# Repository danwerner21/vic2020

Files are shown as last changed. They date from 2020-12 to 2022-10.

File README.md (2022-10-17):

# Vic-2020
A Vic-20 clone created with [almost] all readily available parts

## Introduction
This project is an implementation of a VIC-20 (mostly) compatible computer. The project is built using a combination of 1980's era components (7400-series logic) and more modern components- such as a modern 6502 variant and 512 KiB SRAM and 512 KiB Flash ROMs. The only hard to find component is the MOS 6560 VIC video chip -- and it is my hope to follow up this project with a project to replace that chip with a FPGA replacement, providing the open source community a full path to re-creating the VIC-20 with all new components.

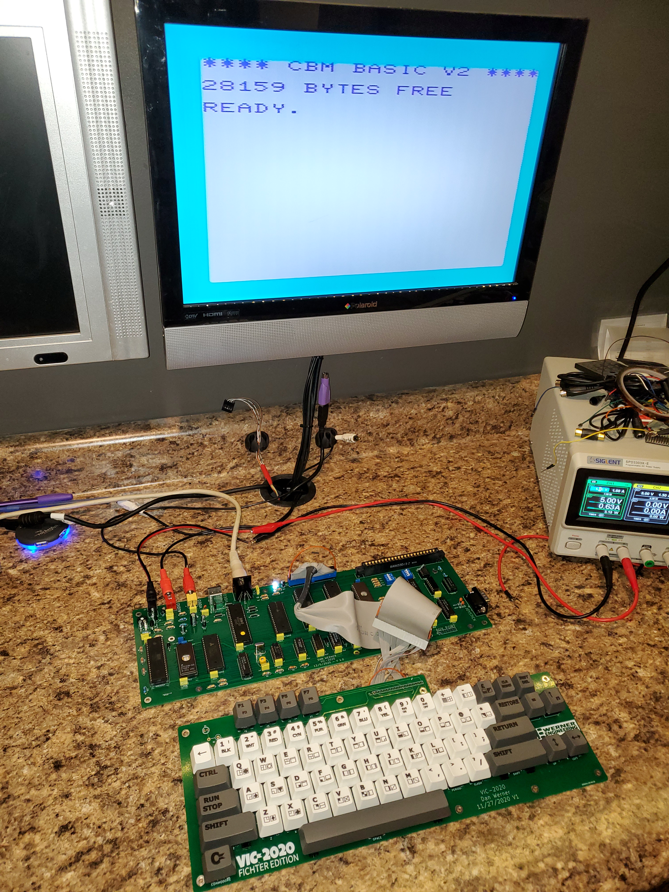
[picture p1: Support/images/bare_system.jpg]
Vic-2020 board set


## Why?
Why would I do a replica of the VIC-20?   Well, like many others the VIC-20 was my first computer.  In 1981 I spent most of my (non-school) waking hours learning everything possible about this machine, and that launched me into a successful career in IT.   In the early 2000s I discovered the retro-computer scene and have spent many hours building and creating new retro computer designs following the work happening in such places as 6502.org and retrobrewcomputers.org.  So much so, that my boss has taken to giving me crap about spending my free time "Building VIC-20s" . . . .   It was earlier in 2020 when he had made one such comment that I realized that while I had constructed many vintage designs, I had never actually built a VIC-20.  I decided that I should correct that oversight as soon as possible -- and thus the VIC-2020 Fichter Edition (named after my boss) was born.

---

## What is included in this repo?
As of this time, the repo includes

1. The VIC-2020 Mainboard PCB Kicad design and Gerber files
2. The VIC-2020 Keyboard PCB Kicad design and Gerber files
3. OpenSCAD and STL files for a 3d printed case
4. Design Files for Max Keyboard Custom Printed Keycaps

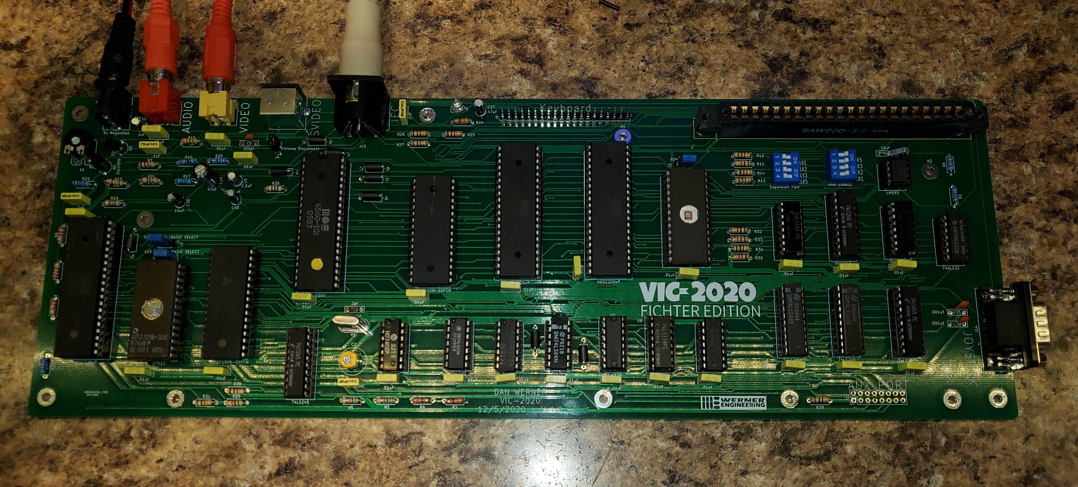
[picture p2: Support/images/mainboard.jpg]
Vic-2020 Mainboard

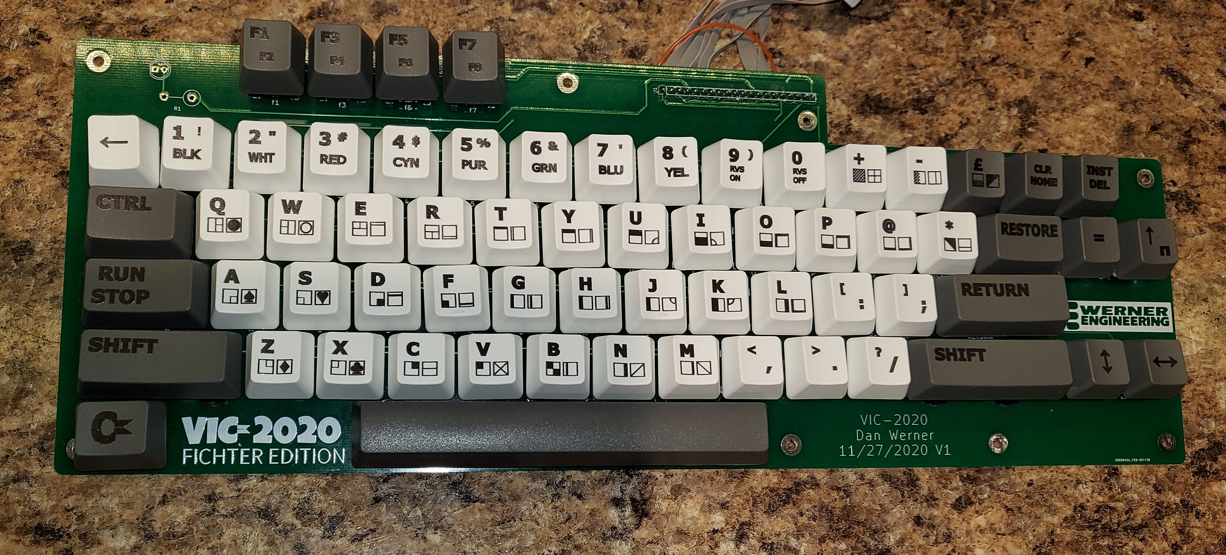
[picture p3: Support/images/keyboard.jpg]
Vic-2020 Keyboard

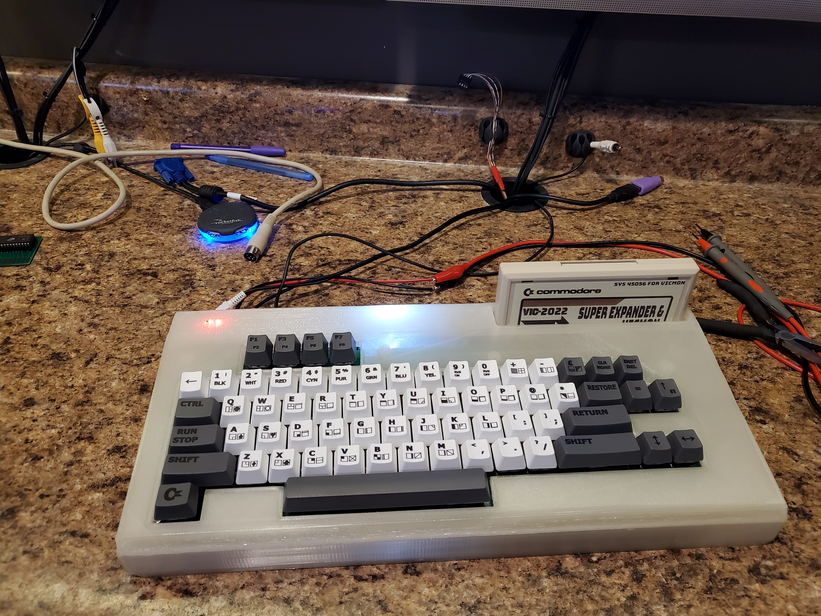
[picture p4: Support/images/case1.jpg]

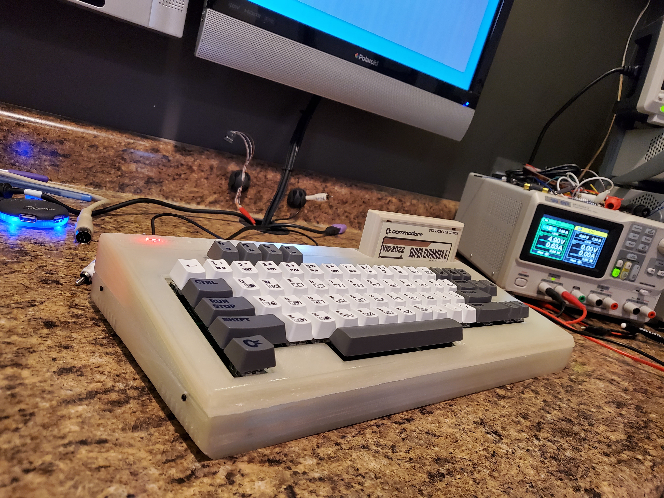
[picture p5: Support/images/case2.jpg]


---

## Known Bugs

* While the mainboard does have a S-VIDEO mod applied that should (in theory) provide S-VIDEO output, it does not work.   If anyone corrects this, please feel free to reach out and I will correct the schematics -- but for now, I would not populate the S-VIDEO connector, and always short the Chroma Disconnect jumper.
#### UPDATE
 Turns out the footprint for the SVIDEO connector in KiCad has the pins numbered incorrectly and that is the cause of the SVIDEO issue.   I have updated the PCB and Schematic to account for this, but have not tested the fix myself.  I am told that the SVIDEO out does work with a properly wired cable.

 note that the 1.1 version of the PCB still have the Chroma/Luma pins reversed on the video connector.  Seems that I made a patch to correct the pins and KiCAD also made a patch to correct the PCB layout of the connector, and thus reversed each other's work. . .  1.2 should be correct, but as always until it is tested, assume it needs patched.

---

## How is the VIC-2020 the same as a VIC-20?

The VIC-2020 should be mostly software compatible with the expanded and unexpanded Commodore VIC-20.   I have tested a variety of cartridges (commodore and third party) and have ran several homebrew and commercial disk based programs on the system with no issues.   Note that this does use a more modern variant of the 6502, so software relying on 6502 undocumented opcodes or bugs will not work properly.  The VIC-2020 has a commodore compatible IEC port that has been tested with a real 1571 and real 1541 and seems to work properly with one exception -- if the device holds the RESET line low the system will not function.   This can be observed if the VIC-2020 is connected to a powered off IED device -- the VIC will not function until the IEC device is powered on or unplugged from the VIC.

---

## How is the VIC-2020 different from a VIC-20?

Because the VIC-2020 is using more modern parts, it has ALOT of ram compared to the VIC-20.   The original VIC-20 shipped with 4k of ram . . .  the VIC-2020 has 256k.  This has some implications.   First, for compatibility there is a portion of the RAM that is just wasted. Of the 128k chip that is used for main memory, only 32k is accessible, the rest is hidden.  This is a design trade off that made the system less complex and ensured compatibility.   That said, small design changes were made to allow the 128k color ram to be totally usable by the system.  The first modification allowed all 8 bits of color ram to be used as storage for the system.  In the original VIC-20, color ram was only 4 bits wide, as the VIC chip only needs 4 bits to store color information.  In the VIC-2020 design all 8 bits are available to the CPU, even though only 4 bits are used by the VIC chip.  This should allow a programmer to store user information in the upper 4 bits of the color ram without affecting any other part of the system.   Also, the 6522 IO port that was dedicated to the user port on the VIC-20 has been repurposed as a "Page Register" (located at 0x9110 or 37136) on the VIC-2020 allowing 128 pages of color ram to be available for the VIC chip.  This should give the ability for some very interesting color effects to be produced on the VIC-2020, while still keeping the VIC mostly compatible.  This technique was demonstrated as early as 2010 in the sleepingelephant.com forums [here](http://sleepingelephant.com/ipw-web/bulletin/bb/viewtopic.php?t=4882).

### Power
Unlike the original, the VIC-2020 will run off of one regulated 5V 1.5A power supply.

### Ports
In order to simplify the VIC-2020s power requirements, the cassette and user ports were ommitted from the system.   It is possible to use the lines in the AUX connector (J11) and the IEC port to gain access to the cassette data lines if one wanted to use a cassette emulator.  The cartridge port is mostly compatible (assuming proper setting of SW3) with the omission of the RAM1,RAM2, & RAM3 lines.
Note that trimmer RV1 can be used to adjust video signal output strength.  If your particular TV appears either overdriven or too dim, adjust RV1 accordingly.   Variable Cap C2 can be used to adjust video signal phase -- adjust this trimmer if your VIC shows no color or the wrong colors.

### Ram Configuration
For simplicity sake, the VIC-2020 in even its lowest memory configuration has the VIC 3K memory expansion enabled at RAM1, RAM2, and RAM3, giving it 8K of base ram, 6.5k free for BASIC.   This configuration is totally compatible with most "unexpanded" VIC software, but is incompatible with any cartridge that includes the 3k RAM expansion option (such as the VIC Super Expander Cartridge).  The other RAM configuration options for BLK1, BLK2, BLK3, and BLK5 are DIP switch selectable allowing memory to be configured.   It is best to have each RAM block only assigned to either the Expansion Port (SW3) or the Internal RAM (SW1) but not both at the same time.  When in doubt set all of SW3 to "on" and all of SW1 to "off" and you should have a mostly compatible unexpanded VIC.  For a mostly compatible expanded VIC set BLK1,BLK2, BLK3 on SW1 to "on" and SW3 to "off".

### Character ROM Configuration
The 8K 2764 EPROM at U19 contains the character ROM image for the VIC-2020.  The VIC chip only needs 4K to store a complete set of character images, so jumper J3 is used to select one of two character sets that can be stored on the 2764.  If pins 1&2 are shorted on the jumper the first 4K of the chip is used (addresses 0x0000-0x0FFF) for the character patterns and if pins 2&3 are shorted the second 4K (addresses 0x1000-0x1FFF) are used.

### System ROM Configuration
On the VIC-2020 it is possible to use several different types of main ROM chips and have several ROM images burned at the same time -- all selected by jumpers J1 and J2.

Jumper Settings|Chip Used|Resulting eprom configuration
---------------|---------|-----------------------
J1 1&2, J2 1&2|27512         | BASIC image at 0x0000 through 0x1FFF KERNAL at 0x2000 through 0x3FFF
J1 1&2, J2 1&2|27256         | BASIC image at 0x0000 through 0x1FFF KERNAL at 0x2000 through 0x3FFF
J1 1&2, J2 1&2|27128         | BASIC image at 0x0000 through 0x1FFF KERNAL at 0x2000 through 0x3FFF
J1 1&2, J2 2&3|27512         | BASIC image at 0x4000 through 0x5FFF KERNAL at 0x6000 through 0x7FFF
J1 1&2, J2 2&3|27256         | BASIC image at 0x4000 through 0x5FFF KERNAL at 0x6000 through 0x7FFF
J1 1&2, J2 2&3|27128         | NOT VALID
J1 2&3, J2 1&2|27512         | BASIC image at 0x8000 through 0x9FFF KERNAL at 0xA000 through 0xBFFF
J1 2&3, J2 1&2|27256         | NOT VALID
J1 2&3, J2 1&2|27128         | NOT VALID
J1 2&3, J2 1&2|27512         | BASIC image at 0xC000 through 0xDFFF KERNAL at 0xE000 through 0xFFFF
J1 2&3, J2 1&2|27256         | NOT VALID
J1 2&3, J2 1&2|27128         | NOT VALID

---

## Bill Of Materials

### Mainboard

Part Number|Quantity|Name
-----------|--------|----
C35,C36	|2|	.001uf Capacitor
C7,C12-C34|	23|	.01uf Capacitor
C1,C6,C8,C10,C40|	5|	.1uf Capacitor
C37	|1|	.47uF Electrolytic Capacitor
C38	|1|	10uF Electrolytic Capacitor
C4	|1|	10uf Capacitor
C11	|1|	1uf Electrolytic Capacitor
C9	|1|	2.2uF Electrolytic Capacitor
C5	|1|	220pf Capacitor
C3	|1|	2pf Capacitor
C39	|1|	47uF Capacitor
C2	|1|	8-90pf  Variable Capacitor
FB1-FB9|	9|	Ferrite_Bead_Small
J1,J2,J3|	3|	Pin Header 1x03 2.54mm
J10	|1|	Barrel Jack
J11	|1|	Pin Header 2x8 2.54mm
J12	|1|	Card Edge Connector 2x22 (Mouser #:587-305-044-520-502)
J13	|1|	DIN 6 IEC connector (mouser#571-9-211509)
J14	|1|	DSUB 9 Male
J4,J9	|2|	Pin Header 1x2 2.54mm
J5	|1|	DIN-4 (mouser#571-5749181-1)
J6,J7	|2|	RCA Jack
J8	|1|	Pin Header 1x20
Q1	|1|	2sc1959
Q2	|1|	2SC1815
R36	|1|	75ohm Resistor 1/4w
R15	|1|	180ohm Resistor 1/4w
R16	|1|	240ohm Resistor 1/4w
R22	|1|	270ohm Resistor 1/4w
R2,R4,R24	|3|	330ohm Resistor 1/4w
R21	|1|	470ohm Resistor 1/4w
R17	|1|	510ohm Resistor 1/4w
R3,R5	|2|	560ohm Resistor 1/4w
R19	|1|	1.8Kohm Resistor 1/4w
R23	|1|	10Kohm Resistor 1/4w
R6	|1|	150Kohm Resistor 1/4w
R7,R11-R14,R18,R25-R35	|16|	1K ohm Resistor 1/4w
R8-R10	|3|	2.2Kohm Resistor 1/4w
R20	|1|	2.7Kohm Resistor 1/4w
R1	|1|	220kohm Resistor 1/4w
RV1	|1|	1Kohm Variable Resistor (Mouser# 531-PT10LV112A22PMS)
SW1,SW3	|2|	DIP Switch 4 pos
U19	|1|	2764
U20	|1|	6560 (MOS, VIC-20 pull or E-Bay)
U1	|1|	7402
U4	|1|	7406
U13	|1|	27512
U24	|1|	74ALS32
U8	|1|	74LS00
U11	|1|	74LS02
U9	|1|	74LS04
U5,U10	|2|	74LS133
U2,U6	|2|	74LS138
U14,U15,U16,U18,U23	|5|	74LS245
U12,U17	|2|	AS6C1008-55PCN
U3	|1|	LM555
U7	|1|	W65C02SxP
U21,U22	|2|	W65C22NxP
Y1	|1|	Crystal 14.31818Mhz

### Keyboard

Quantity|Name
--------|----
65|Cherry MX Switch | (Example Mouser 540-MX1A-11NW)
4|Switch Leveling Kit| Mouser 540-G99-0226 Note: Use one of 540-G99-0742 to build a through hole leveling kit for the spacebar
1|Pin Header 1x20
1|Pin Header 1x2 or LED
1|330 Ohm Resistor
1| Keycap set (See Max Keyboard Template to order custom keycaps)
1| 1x20 Female to Female dupont connector ribbon cable to connect keyboard to mainboard

### Case

The case for the Vic-2020 was created using openSCAD and was printed on the AnyCubic Chiron large format printer.   The OpenSCAD source files and the STL files are included in the archive.  The case is designed to allow you to install a power led in the upper left corner.   The opening is intended for two rectangular LEDs glued as shown here:

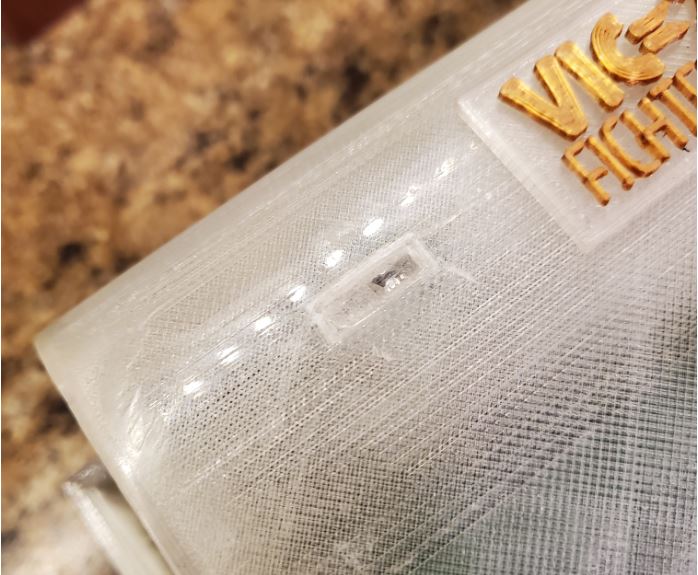
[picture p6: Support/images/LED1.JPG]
Case LED

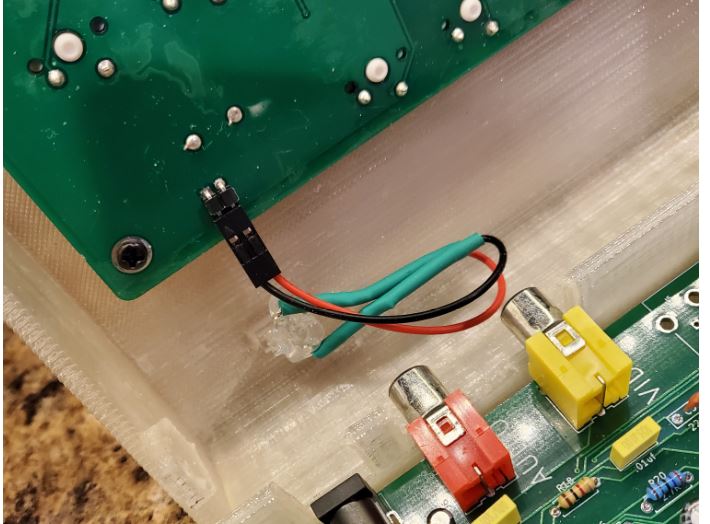
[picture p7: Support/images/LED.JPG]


It is also necessary to install a stabilizer on one corner of the keyboard to ensure that the keyboard PCB does not flex while typing.  This is how I did it:

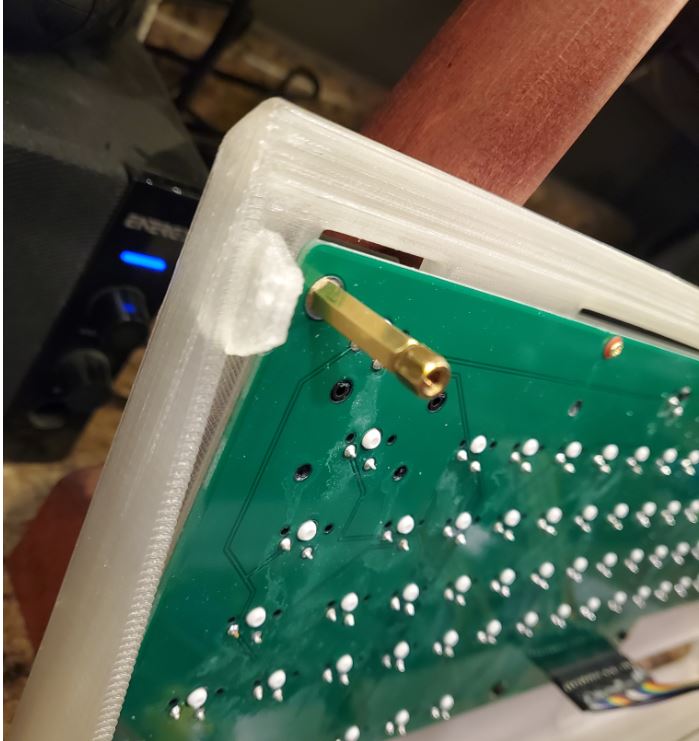
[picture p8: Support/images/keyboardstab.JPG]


When complete, the interior of the 3d printed case will look like this:

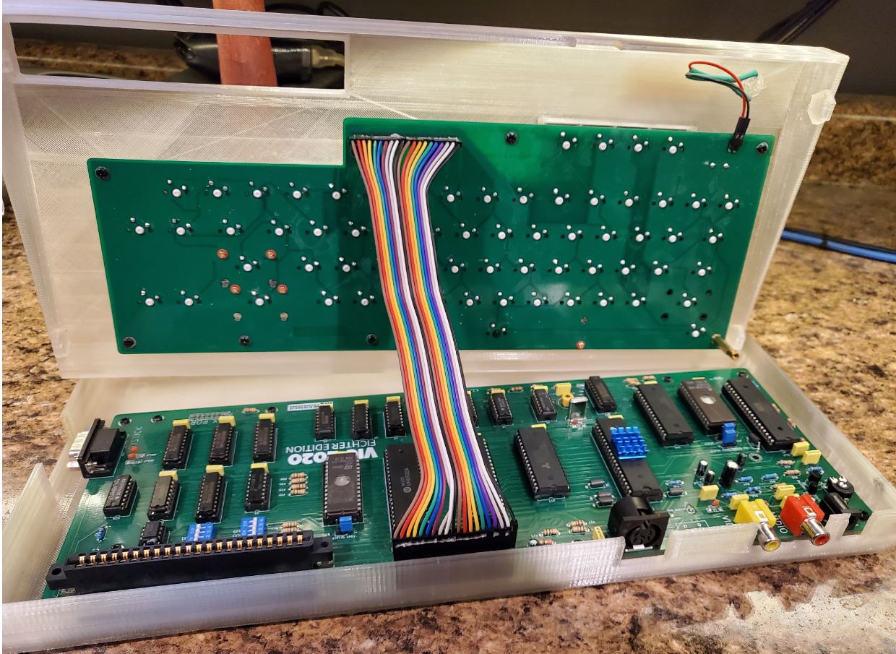
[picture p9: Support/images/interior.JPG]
Case internal


### Builder Comments

Below is a couple of observations from builders that might be useful in your build.  I have not tested any of these suggestions, just passing on collective wisdom :)

* One bulder commented that he needed to replace U9 (74LS04->74F04) and U11 (74LS02->74F02) with F series logic in order to get clean RAM access.   I have not had a need to do this on any of my builds, but timing is very tight on this board, and it is always possible that these substitutions would help clear up issues.  This same builder needed to use a Rockwell 65C02 in place of the WDC 65C02 to get a stable build.

* Another builder noted that is is important to use a 2764 EPROM for the character ROM.   A 27C64 EPROM caused graphical glitching when used.

* It was recently reported that at least one builder has had success using a 6561 PAL VIC chip to replace the 6560 NTSC VIC chip.  It is also necessary to replce the 14.31818Mhz crystal with a 4.433618 MHz crystal in a PAL system.

### Questions?

If there are any questions, I can be reached at vic2020Dan at gmail dot com.

---

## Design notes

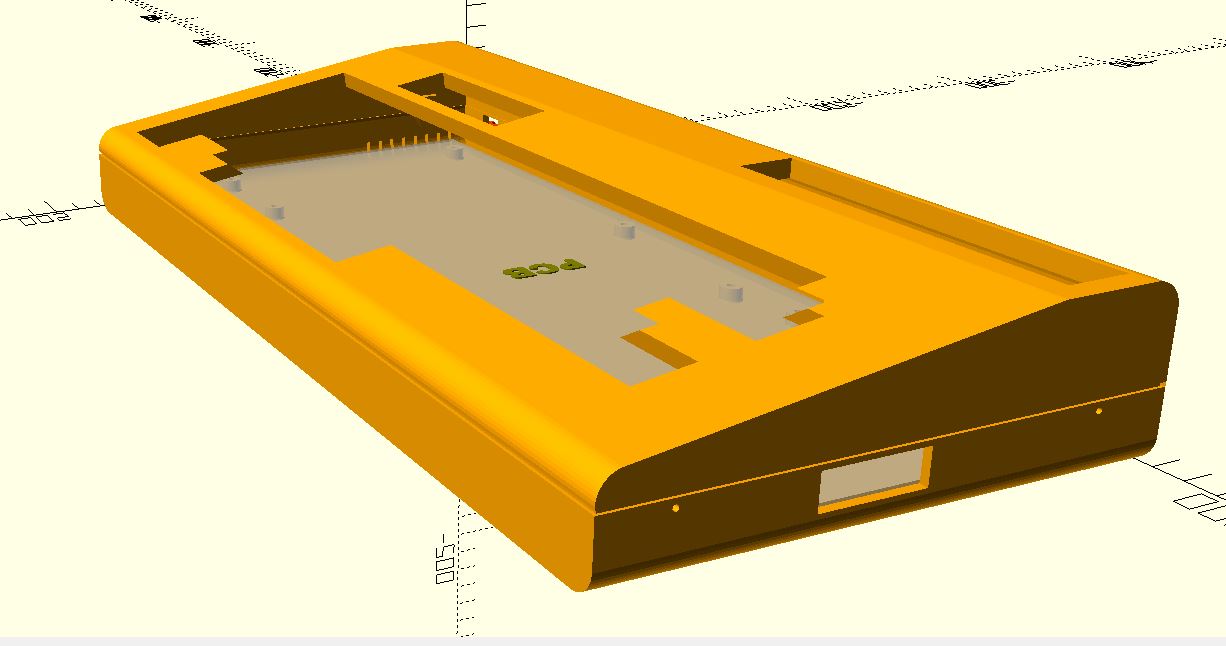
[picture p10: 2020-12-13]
Support/images/Case Render2.JPG

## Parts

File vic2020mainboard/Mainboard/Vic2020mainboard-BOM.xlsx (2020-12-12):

Reference | Qty | Value | Source
C35,C36 | 2 | .001uf Capacitor | mouser# 594-S102M33Z5UR63L6R
C7,C12-C34 | 23 | .01uf Capacitor | Capacitor_THT:C_Rect_L7.0mm_W2.0mm_P5.00mm
C1,C6,C8,C10,C40 | 5 | .1uf Capacitor | Capacitor_THT:C_Rect_L7.0mm_W2.0mm_P5.00mm
C37 | 1 | .47uF Electrolytic Capacitor | Capacitor_THT:CP_Radial_D4.0mm_P2.00mm
C38 | 1 | 10uF Electrolytic Capacitor | Capacitor_THT:CP_Radial_D4.0mm_P2.00mm
C4 | 1 | 10uf Capacitor | Capacitor_THT:C_Rect_L7.0mm_W2.0mm_P5.00mm
C11 | 1 | 1uf Electrolytic Capacitor | Capacitor_THT:CP_Radial_D4.0mm_P2.00mm
C9 | 1 | 2.2uF Electrolytic Capacitor | Capacitor_THT:CP_Radial_D4.0mm_P2.00mm
C5 | 1 | 220pf Capacitor | Capacitor_THT:C_Rect_L7.0mm_W2.0mm_P5.00mm
C3 | 1 | 2pf Capacitor | Capacitor_THT:C_Rect_L7.0mm_W2.0mm_P5.00mm
C39 | 1 | 47uF Capacitor | Capacitor_THT:CP_Radial_D4.0mm_P2.00mm
C2 | 1 | 8-90pf Variable Capacitor | Capacitor_THT:C_Radial_D10.0mm_H12.5mm_P5.00mm
FB1-FB9 | 9 | Ferrite_Bead_Small | Inductor_THT:L_Axial_L6.6mm_D2.7mm_P10.16mm_Horizontal_Vishay_IM-2
J1,J2,J3 | 3 | Pin Header 1x03 2.54mm | Connector_PinHeader_2.54mm:PinHeader_1x03_P2.54mm_Vertical
J10 | 1 | Barrel Jack | Connector_BarrelJack:BarrelJack_CUI_PJ-063AH_Horizontal
J11 | 1 | Pin Header 2x8 2.54mm | Connector_PinHeader_2.54mm:PinHeader_2x08_P2.54mm_Vertical
J12 | 1 | Card Edge Connector 2x22 (Mouser #:587-305-044-520-502) | Mouser #:587-305-044-520-502
J13 | 1 | DIN 6 IEC connector (mouser#571-9-211509) | 587-305-044-520-502
J14 | 1 | DSUB 9 Male | Connector_Dsub:DSUB-9_Male_Horizontal_P2.77x2.84mm_EdgePinOffset4.94mm_Housed_MountingHolesOffset7.48mm
J4,J9 | 2 | Pin Header 1x0 2.54mm | Connector_PinHeader_2.54mm:PinHeader_1x02_P2.54mm_Vertical
J5 | 1 | DIN-4 (mouser#571-5749181-1) | Connector:DIN-4TE_5749181-1
J6,J7 | 2 | RCA Jack | RCA:CUI_RCJ-041-reversepins
J8 | 1 | Pin Header 1x20 | Connector_PinHeader_2.54mm:PinHeader_1x20_P2.54mm_Vertical
Q1 | 1 | 2sc1959 | Package_TO_SOT_THT:TO-92_Inline_Wide
Q2 | 1 | 2SC1815 | Package_TO_SOT_THT:TO-92_Inline_Wide
R36 | 1 | 75ohm Resistor 1/4w | Resistor_THT:R_Axial_DIN0207_L6.3mm_D2.5mm_P7.62mm_Horizontal
R15 | 1 | 180ohm Resistor 1/4w | Resistor_THT:R_Axial_DIN0207_L6.3mm_D2.5mm_P7.62mm_Horizontal
R16 | 1 | 240ohm Resistor 1/4w | Resistor_THT:R_Axial_DIN0207_L6.3mm_D2.5mm_P7.62mm_Horizontal
R22 | 1 | 270ohm Resistor 1/4w | Resistor_THT:R_Axial_DIN0207_L6.3mm_D2.5mm_P7.62mm_Horizontal
R2,R4,R24 | 3 | 330ohm Resistor 1/4w | Resistor_THT:R_Axial_DIN0207_L6.3mm_D2.5mm_P7.62mm_Horizontal
R21 | 1 | 470ohm Resistor 1/4w | Resistor_THT:R_Axial_DIN0207_L6.3mm_D2.5mm_P7.62mm_Horizontal
R17 | 1 | 510ohm Resistor 1/4w | Resistor_THT:R_Axial_DIN0207_L6.3mm_D2.5mm_P7.62mm_Horizontal
R3,R5 | 2 | 560ohm Resistor 1/4w | Resistor_THT:R_Axial_DIN0207_L6.3mm_D2.5mm_P7.62mm_Horizontal
R19 | 1 | 1.8Kohm Resistor 1/4w | Resistor_THT:R_Axial_DIN0207_L6.3mm_D2.5mm_P7.62mm_Horizontal
R23 | 1 | 10Kohm Resistor 1/4w | Resistor_THT:R_Axial_DIN0207_L6.3mm_D2.5mm_P7.62mm_Horizontal
R6 | 1 | 150Kohm Resistor 1/4w | Resistor_THT:R_Axial_DIN0207_L6.3mm_D2.5mm_P7.62mm_Horizontal
R7,R11-R14,R18,R25-R35 | 16 | 1K ohm Resistor 1/4w | Resistor_THT:R_Axial_DIN0207_L6.3mm_D2.5mm_P7.62mm_Horizontal
R8-R10 | 3 | 2.2Kohm Resistor 1/4w | Resistor_THT:R_Axial_DIN0207_L6.3mm_D2.5mm_P7.62mm_Horizontal
R20 | 1 | 2.7Kohm Resistor 1/4w | Resistor_THT:R_Axial_DIN0207_L6.3mm_D2.5mm_P7.62mm_Horizontal
R1 | 1 | 220kohm Resistor 1/4w | Resistor_THT:R_Axial_DIN0207_L6.3mm_D2.5mm_P7.62mm_Horizontal
RV1 | 1 | 1Kohm Variable Resistor (Mouser# 531-PT10LV112A22PMS) | Varistor:Potentiometer_Trimmer_2x4.kicad_mod
SW1,SW3 | 2 | DIP Switch 4 pos | Package_DIP:DIP-8_W7.62mm
U19 | 1 | 2764 | Package_DIP:DIP-28_W15.24mm_Socket
U20 | 1 | 6560 (MOS, VIC-20 pull or E-Bay) | Package_DIP:DIP-40_W15.24mm_Socket
U1 | 1 | 7402 | Package_DIP:DIP-14_W7.62mm_Socket
U4 | 1 | 7406 | Package_DIP:DIP-14_W7.62mm_Socket
U13 | 1 | 27512 | Package_DIP:DIP-28_W15.24mm
U24 | 1 | 74ALS32 | Package_DIP:DIP-14_W7.62mm_Socket
U8 | 1 | 74LS00 | Package_DIP:DIP-14_W7.62mm_Socket
U11 | 1 | 74LS02 | Package_DIP:DIP-14_W7.62mm_Socket
U9 | 1 | 74LS04 | Package_DIP:DIP-14_W7.62mm_Socket
U5,U10 | 2 | 74LS133 | Package_DIP:DIP-16_W7.62mm_Socket
U2,U6 | 2 | 74LS138 | Package_DIP:DIP-16_W7.62mm_Socket
U14,U15,U16,U18,U23 | 5 | 74LS245 | Package_DIP:DIP-20_W7.62mm_Socket
U12,U17 | 2 | AS6C1008-55PCN | Package_DIP:DIP-32_W15.24mm
U3 | 1 | LM555 | Package_DIP:DIP-8_W7.62mm_Socket
U7 | 1 | W65C02SxP | Package_DIP:DIP-40_W15.24mm_Socket
U21,U22 | 2 | W65C22NxP | Package_DIP:DIP-40_W15.24mm_Socket
Y1 | 1 | Crystal 14.31818Mhz | Crystal:Crystal_HC18-U_Vertical

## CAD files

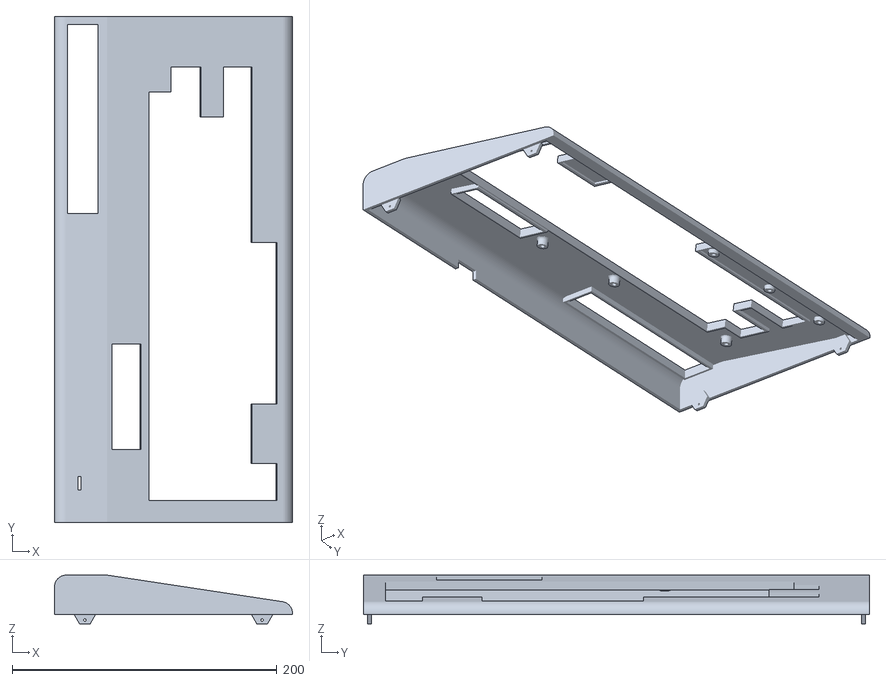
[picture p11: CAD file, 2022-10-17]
Support/Vic2020case_Top.stl
180.0 x 382.5 x 36.9

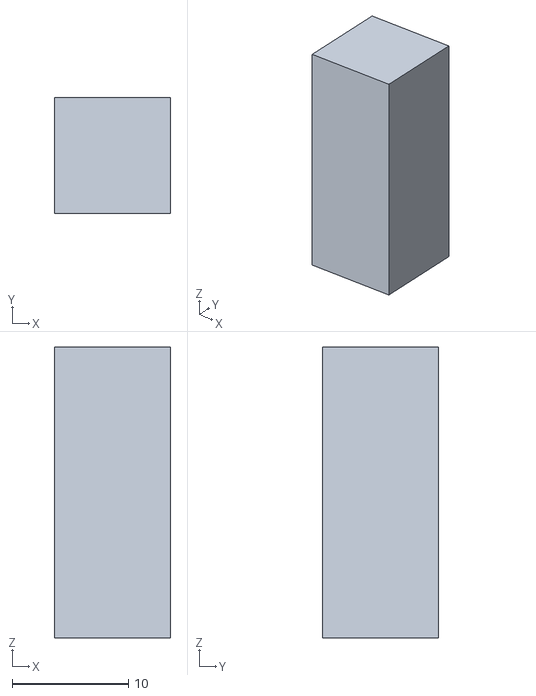
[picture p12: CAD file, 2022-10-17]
Support/Vic2020case_Keyboard_spacer.stl
10.0 x 10.0 x 25.0

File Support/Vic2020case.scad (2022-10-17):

/* [Box dimensions] */
  Length        = 180;       
  Width         = 385;                     
  TopHeight        = 10;  
  BottomHeight     = 25;  
  SlopeHeight      = 20;
  Thick         = 3;


  
/* [Box options] */
  PCBFeet       = 1;// [0:No, 1:Yes]
  Vent          = 1;// [0:No, 1:Yes]
  Vent_width    = 1.5;   



  Filet         = 9;//[0.1:12] 
  Resolution    = 50;//[1:100] 
  m             = 0.9;
  
/* [PCB_Feet--the_board_will_not_be_exported) ] */
//All dimensions are from the center foot axis
PCBPosX         = 0;
PCBPosY         = 0;
PCBLength       = 125;
PCBWidth        = 358;
FootHeight      = 9;
FootDia         = 8;
FootHole        = 4.4;  
  

/* [STL element to export] */
  TShell        = 0;// [0:No, 1:Yes]
  BShell        = 1;// [0:No, 1:Yes]
  RLogo         = 0;// Logo
  Spacer         = 0;// keyboard Spacer


  
/* [Hidden] */
Couleur1        = "Orange";       
Couleur2        = "OrangeRed";    
Dec_Thick       = Vent ? Thick*2 : Thick; 
Dec_size        = Vent ? Thick*2 : 0.8;

PCBL=PCBLength;
PCBW=PCBWidth;

   
module SlopeRoundBox($a=Length, $b=Width, $c=TopHeight+BottomHeight){
                    $fn=Resolution;     
                         
                        translate([Filet,-Filet/2,Filet])
                        {  
                    minkowski ()
                    {  
              
                    translate([0,($b/2)+1,TopHeight])
                       rotate(a=[0,-90,90])
                          linear_extrude(height =(($b/2)-Filet/2)+1, center = false, convexity = 0, twist = 0)
                              polygon(points=[[0,0],[(SlopeHeight+TopHeight)*-1,0],[(SlopeHeight+TopHeight)*-1,-30],  [TopHeight*-1,($a-Filet*2)*-1],[0,($a-Filet*2)*-1]], paths=[[3,2,1,0]]);                      
                        
                     rotate([270,0,0]){    
                        cylinder(r=Filet,h=Width/2+1, center = false);
                            } 
                        }
                    }
                }// End of RoundBox Module                


module RoundBox($a=Length, $b=Width, $c=TopHeight+BottomHeight){
                    $fn=Resolution;            
                    translate([0,Filet,Filet]){  
                    minkowski (){                                              
                        cube ([$a-(Length/2),$b-(2*Filet),$c-(2*Filet)], center = false);
                        rotate([0,90,0]){   
                           translate([0,0,Filet]){  
                        cylinder(r=Filet,h=Length/2-(2*Filet), center = false);}
                            } 
                        rotate([270,0,0]){    
                        cylinder(r=Filet,h=.1, center = false);
                            } 
                        }
                    }
                }// End of RoundBox Module



module TopShell(){
    Thick = Thick*2;  
    difference(){    
        difference(){
            union(){    
                     difference() {
                      
                        difference(){
                            union() {
                                        KeyboardCutoutReinforcement();

                            difference(){
                                SlopeRoundBox();
                                translate([Thick/2,Thick/2,Thick/2]){     
                                        SlopeRoundBox($a=Length-Thick*2, $b=Width-Thick*2, $c=TopHeight+BottomHeight-Thick);
                                        }
                                        }
                                    }
                               translate([-Thick,-Thick,TopHeight]){
                                   cube ([Length+100, Width+100, TopHeight+BottomHeight], center=false);
                                            }                                            
                                      }
                                }                                          

                difference(){
                    union(){
                        translate([3*Thick +5,Thick,TopHeight]){
                            rotate([90,0,0]){
                                    $fn=6;
                                    cylinder(d=16,Thick/2);
                                    }   
                            }
                            
                       translate([Length-((3*Thick)+5),Thick,TopHeight]){
                            rotate([90,0,0]){
                                    $fn=6;
                                    cylinder(d=16,Thick/2);
                                    }   
                            }

                    translate([3*Thick +5,Width-Thick/2-2.4,TopHeight]){
                            rotate([90,0,0]){
                                    $fn=6;
                                    cylinder(d=16,Thick/2);
                                    }   
                            }
                            
                       translate([Length-((3*Thick)+5),Width-Thick/2-2.4,TopHeight]){
                            rotate([90,0,0]){
                                    $fn=6;
                                    cylinder(d=16,Thick/2);
                                    }   
                            }


                        }
                            
                    } 
                    
                    
            }

       }


///Put Difference Keyboard Cutout Here

            union(){ //sides holes
                $fn=50;
                translate([3*Thick+5,20,TopHeight+4]){
                    rotate([90,0,0]){
                    cylinder(d=2,20);
                    }
                }
                translate([Length-((3*Thick)+5),20,TopHeight+4]){
                    rotate([90,0,0]){
                    cylinder(d=2,20);
                    }
                }
                translate([3*Thick+5,Width+5,TopHeight+4]){
                    rotate([90,0,0]){
                    cylinder(d=2,20);
                    }
                }
                translate([Length-((3*Thick)+5),Width+5,TopHeight+4]){
                    rotate([90,0,0]){
                    cylinder(d=2,20);
                    }
                }
            }

         // IEC Opening    
            translate([-1,(Thick)+243.8,Thick-3]){
              cube([21,21,BottomHeight-7]);
            }   


        KeyboardCutout();

        }
        KeyboardFeet();
        
       

}





module BottomShell(){
    Thick = Thick*2;  
    translate([0,2,0]){
    
    difference(){    
        difference(){
            //Main Box
            union(){    
                     difference() {
                      
                        difference(){
                            union() {
                            difference(){
                                RoundBox($a=Length, $b=Width-2, $c=TopHeight+BottomHeight);
                                translate([Thick/2,Thick/2,Thick/2]){     
                                        RoundBox($a=Length-Thick, $b=Width-Thick-2, $c=TopHeight+BottomHeight-Thick);
                                        }
                                        }

                                    }
                               translate([-Thick,-Thick,BottomHeight]){
                                   cube ([Length+100, Width+100, TopHeight+BottomHeight], center=false);
                                            }                                            
                                      }
                                }                                          


              
            }

       
            // vent holes
            union(){           
            for(i=[0:Thick:Length/4]){
                    translate([10+i,-Dec_Thick+Dec_size,1]){
                    cube([Vent_width,Dec_Thick,BottomHeight/2]);
                    }
                    translate([(Length-10) - i,-Dec_Thick+Dec_size,1]){
                    cube([Vent_width,Dec_Thick,BottomHeight/2]);
                    }
               
                  }
                }
                
        
            // Joystick Opening    
            translate([79,Width-Dec_size-2,Thick+4]){    
              cube([35,Dec_Thick+2,BottomHeight-5]);
            }
                

            // Power Opening    
            translate([-1,(Thick)+13.6,Thick+4]){
              cube([12,13,BottomHeight-11]);
            }   

            // Audio Opening    
            translate([-1,(Thick)+33.7,Thick+4]){
              cube([12,13,BottomHeight-11]);
            }   

            // Video Opening    
            translate([-1,(Thick)+55.5,Thick+4]){
              cube([12,13,BottomHeight-11]);
            }   

            // S-Video Opening    
          //  translate([-1,(Thick)+78.5,Thick+4]){
         //     cube([15,16,BottomHeight-9]);
         //   }
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

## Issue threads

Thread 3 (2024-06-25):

more for collective wisdom (things I've learnt along the way)

giobbino, 2024-06-25:
Finally I got a boot screen so I wish to share my experience with future builders...

- I do confirm that you can use PAL 6561-101 VIC chip. You need to use a 4.433618 MHz crystal (as as described in the readme.md) **AND** the PAL Kernal.
For the sake of simplicity, I'm attaching here a zip with the PAL Kernal ROM (both 256k and 512k). It also include a dual char ROM; you can swap between VIC-20 and C=64 characters generator (I've noticed you can swap it on the fly, without to switch off the computer).

[VIC2020 PAL kernal and char ROM.zip](https://github.com/user-attachments/files/15962549/VIC2020.PAL.kernal.and.char.ROM.zip)

- I also can confirm that you can use ATMEL AT28C256 for Basic + Kernal and ATMEL AT28C64 for char generator. I tried a Thompson 2764A EPROM, but it didn't work for me.

- Due to a different architecture from the original VIC-20, You **MUST** place the two 65C22 chips (U21 and U22) into their own sockets or the computer will not boot _(different from the Commodore computers, from PET, to VIC-20, C=64 and so on, where you usually remove those two chips during the debugging operation, since they're not needed for the computer to boot, but can lead to a black screen if bad)_

I'm using Rockwell R65C02 and R65C22, and some 74F chips as described in the readme.md

------

Now I'm going to build the keyboard, I was happy to see the welcome screen after some initial issues, so I decided to resume here some suggestions before to forget what I did.

danwerner21, 2024-06-26:
appreciate the feedback!  I will get this added to the readme file as soon as I get some time!

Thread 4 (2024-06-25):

suggestion about the cartridge connector

giobbino, 2024-06-25:
On Aliexpress (that, for many of us, is way cheaper than Mouser, also due to the shipping fee) you can find only this type of edge connector for that pitch (I didn't find any other):

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

Unfortunately it has bigger pins than the respective holes on the mainboard. I will try to drill the mainboard a little to fit that connector, but you maybe would update the Gerber with bigger holes for future builders.

Cheers,
Giovi

danwerner21, 2024-06-26:
appreciate the feedback, will try to get it incorporated in!

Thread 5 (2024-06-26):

it hardly boots

giobbino, 2024-06-26:
(Note: I suspect the issue I'm having have to do with fake ICs, especially fake Rockwell 65C02 / 65C22).

When I power on the board, usually does nothing, not even a black screen. It's totally out of signal, no raster.
At the beginning I suspected it was something (spike?) related with the lack of a power-on switch, so I added one. No changes.

However I noticed If I give a little tap on the switch, removing the power to the board for a very little instant (enough for the LED to blink, however), often the computer boot or at least starts to boot: mostly it lead to a black screen (with raster) that can converted in a normal boot screen using a reset switch between pins #3 and #8 of the 555.

I also noticed that the same behavior happens with a fake MOS 6502 I've bought on Aliexpres for a couple of bucks (so this leads me to believe the Rockwell 65C02 is a fake too).

Any idea about how to solve this problem?  BTW I've seen the decoupling capacitors are all 10 uF, while in most projects is used the 100 uF. Could it have something to do with that?

I've bought some more Rockwell ICs, but nobody grants they're legit and not (again!) fake. Unfortunately buying from Mouser or Digikey is not feasible; shipping to Brazil would cost more than 50 US$, because the haven't a cheap shipping option like Aliexpress.

danwerner21, 2024-06-26:
I am not sure about the fake 65C02s -- I have not had that issue (I usually do not use aliexpress -- for that very reason).

There are a couple of other things you might check though.   There are a few chips where logic family REALLY matters.   I would make sure that U4 is a 7406 and not a 74LS06 or any other family.   Same with U1 -- the 7402 needs to be a 7402.  The last important one is U24 -- it needs to be a 74ALS32.

Checking those chips would be the first place I would start looking.

Dan

giobbino, 2024-06-27:
Dan, thanks for your answer, it seems you pointed me in the right direction, albeit the results are different from the expected.

At first I did a test I should have done before: I checked with the scope the wave signal at the crystal pins... result, when the computer didn't boot there was a  very strange wave frequency (13.2 MHz) or just some noisy wave at 38.2 Mhz). So I replaced the crystal and later also the variable capacitor. No changes.

Of course I used 7606, 73ALS32 and 7402. I got this last one from my working, fully socketed VIC-20 I uses for tests etc. - BTW _The interesting part is that I replaced it with a 74LS02 and the VIC-20 still worked fine._

The 7402 I got from the VIC-20 had quite a recent date stamp; so I began wondering if it could be a fake CMOS labelled as 7402 as sometimes/often happens (however for some reason it worked into the VIC-20).

Since the VIC-20 worked fine with a 74LS02 in place of the 7402, I thought "why not?"... I got an old, legit 74LS02 and I put in the VIC2020.

Result: now the VIC2020 works fine, or at least it didn't fail anymore. So apparently a good 74LS02 in place of the 7402 can be used for the VIC2020. I will keep testing it and keep you informed.

My question is: what is the difference between 74 and 74LS ? AFAIK both should be NMOS, and LS was just a lower mA... and I can't find any different answer from the web.

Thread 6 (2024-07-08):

S-VIDEO / AUDIO correction

kinmami, 2024-07-08:
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

h[ttps://www.pcbway.com/project/shareproject/Commodore_VIC_20_MOS_6560_6561_Audio_Video_Booster_Adapter_726e273e.html](url)

To correct and improve the video and audio circuit of the MOS 6560/6561, please refer to my project and schematic. I hope it proves helpful. Regards, Edoardo

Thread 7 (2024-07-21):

VIC2020 and Tapuino

giobbino, 2024-07-21:
Hi,
I've built the first one, adding inside an SD2IEC, and now I'm planning to build the second and last one, but this I wish to put inside a Tapuino with display and buttons directly integrated into the case.

You said on could use the aux and iec ports for that purpose, but I don't understand how.
Can you kindly explain how to connect a Tapuino to the VIC2020?

BTW there are many versions of the Tapuino; the link to simple the project I'm going to use is: https://github.com/sweetlilmre/tapuino

danwerner21, 2024-07-21:
Sorry, but I do not know much about the tapunio  . . . but I expect would think that  what you are suggesting will work just fine.

giobbino, 2024-07-21:
Thanks for your answer! My only doubt, before to do a test, was about the WRITE line. I will try soon and report here the result!

BTW Tapuino is just a datassette emulator; it uses all the datassette lines, but of course - since it has no motor - it doesn't drain almost any power from the motor line.
The motor line is used to switch on/ff the IR transmitter of an optocoupler. I'm not sure if the 6522 supplies enough power for that, but just in case, a transistor should solve. I will take a look to the 6522 datasheet to see if I can any useful info there.

giobbino, 2024-07-23:
OK, i got the thing working in my 2nd VIC-2020 :-)

As told before, I used this version of Tapuino: [https://github.com/sweetlilmre/tapuino](https://github.com/sweetlilmre/tapuino) that's cheap, easy to build and can be embedded into the VIC-2020 _(I will put the display and the button in the place of the cartridge port, modifying the 3D project, since I don't need it - I have enough VIC-20s for that purpose and however I don't use cartridges a lot...  actually I seldom use the VIC-20, and I don't even know why I've built two VIC-2020 LOL)_

However, it requires some little modifications.

1) the AUX connector pin #16 must to be repurposed: cut the copper trace, check with a multimeter that it's no longer connected to GND and link it with a piece of wire to U22 pin #13. That's the WRITE line _(BTW strange that the aux connector hasn't it natively... maybe in a future revision?)_

2) the motor line is HIGH when the motor is off, and LOW when the motor is on; in the real VIC-20 it is connected to a small circuit of 3 transistors that inverts the signal and also add the needed power to move the C2N motor, but for the Tapuino we need to manage it someway.
In the attached schematics (see below, please forgive me the rather bad design LOL) you can find the modification at the original Tapuino schematics. It will require just an NPN transistor (I used a BC547 and it worked well).

In Tapuino, don't forget to enter into the Options and set Machine = VIC.

Hope it could help somebody.

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

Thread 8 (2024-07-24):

Equivalent ICs that worked (for me)...

giobbino, 2024-07-24:
Hi,
I just wish to leave some more info for the future builders...

NOTE: MY VERSION IS PAL (6561-101 and 4.433618 Mhz crystal) - some components listed here could not work in the NTSC version.

This is the logic glue I tested. What is not listed here is because I didn't test since I haven't different IC version in my tool box (74LS133, 74LS04 and 7406).

74ALS32  --> 74HC32; 74LS32
74LS245   --> 74HCT245
74LS138   --> 74HCT138
74LS02 	 --> 74HCT02
7402	 --> 74LS02  _(but not 74HCT02)_
74LS00     --> 74HCT00

I also verified that original MOS 6502 and MOS 6522 work too.

More: I tested those "fake MOS" 6502 that you can find for a couple of bucks or less on Aliexpress: they work too!

Actually those 6502  aren't fake 6502, just the "MOS" label is. They work; sometimes in a bunch of five or ten you can find one that  doesn't, but usually they're all ok. I suppose they're 6502 that come from some bad lot; they sanded the original label and wrote another one... so it could happen that after few days/months or in a specific configuration can hang...  but it's just what I'm guessing; I've not did an extensive test yet.

danwerner21, 2024-09-17:
Thanks for the feedback, I will try to get this incorporated into the README file!

Dan

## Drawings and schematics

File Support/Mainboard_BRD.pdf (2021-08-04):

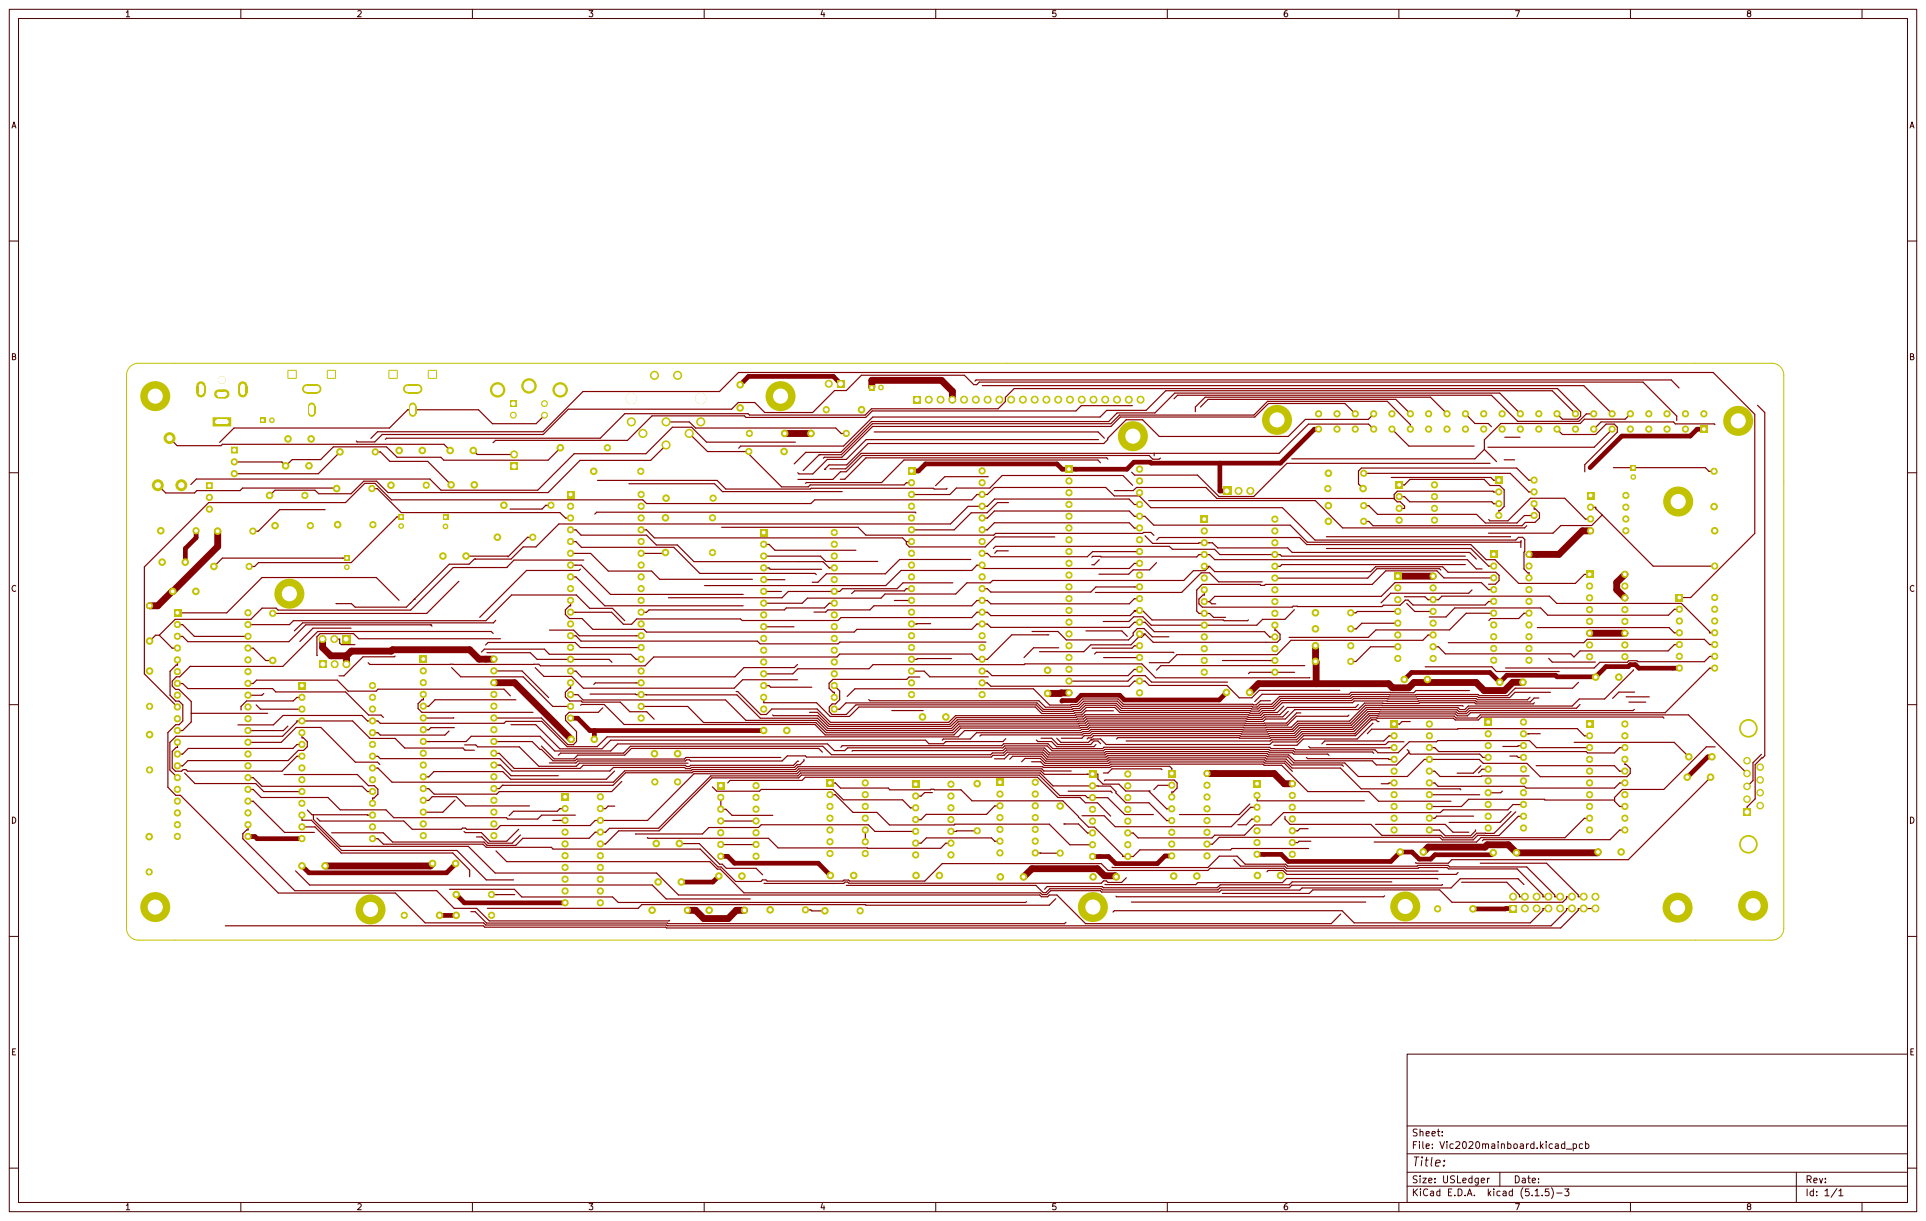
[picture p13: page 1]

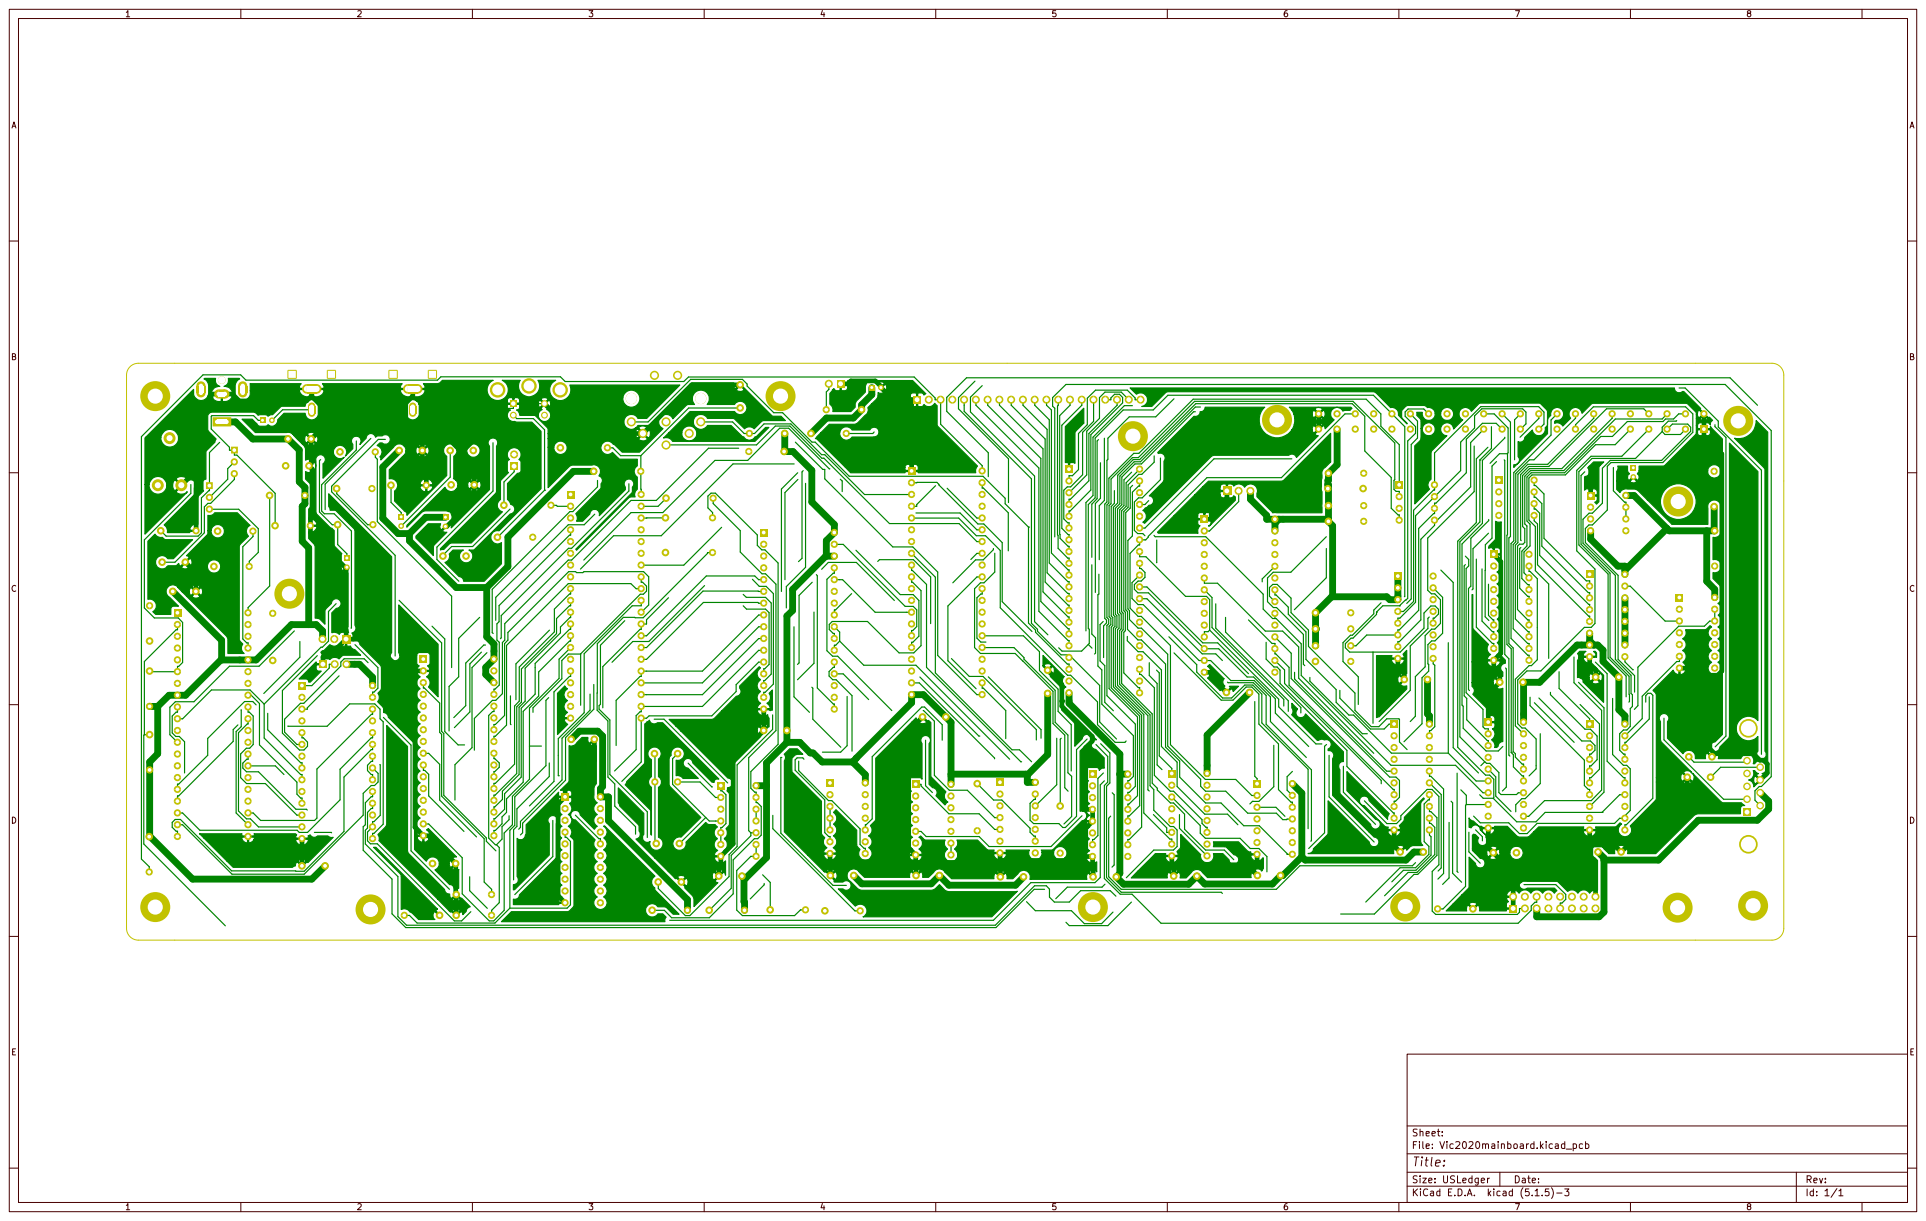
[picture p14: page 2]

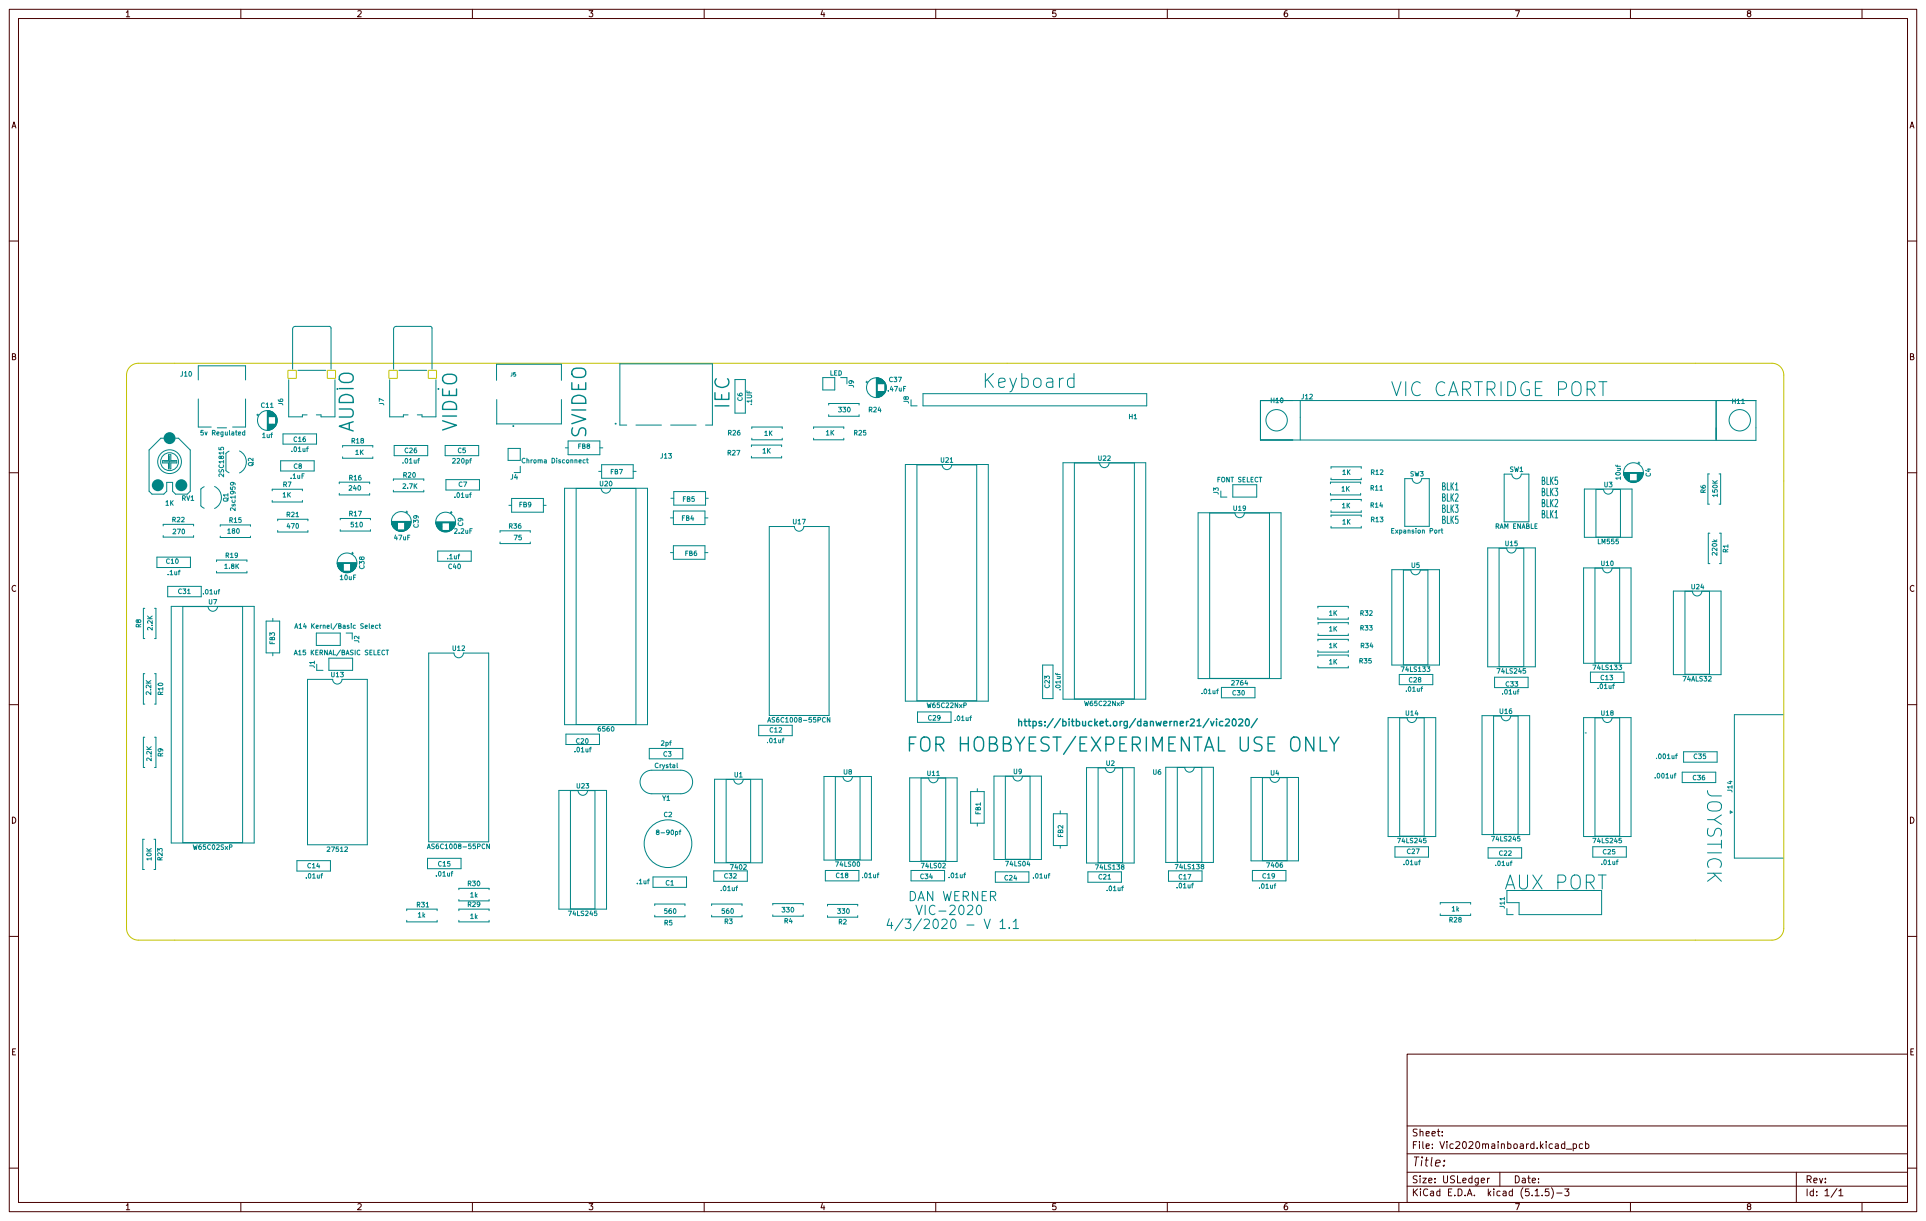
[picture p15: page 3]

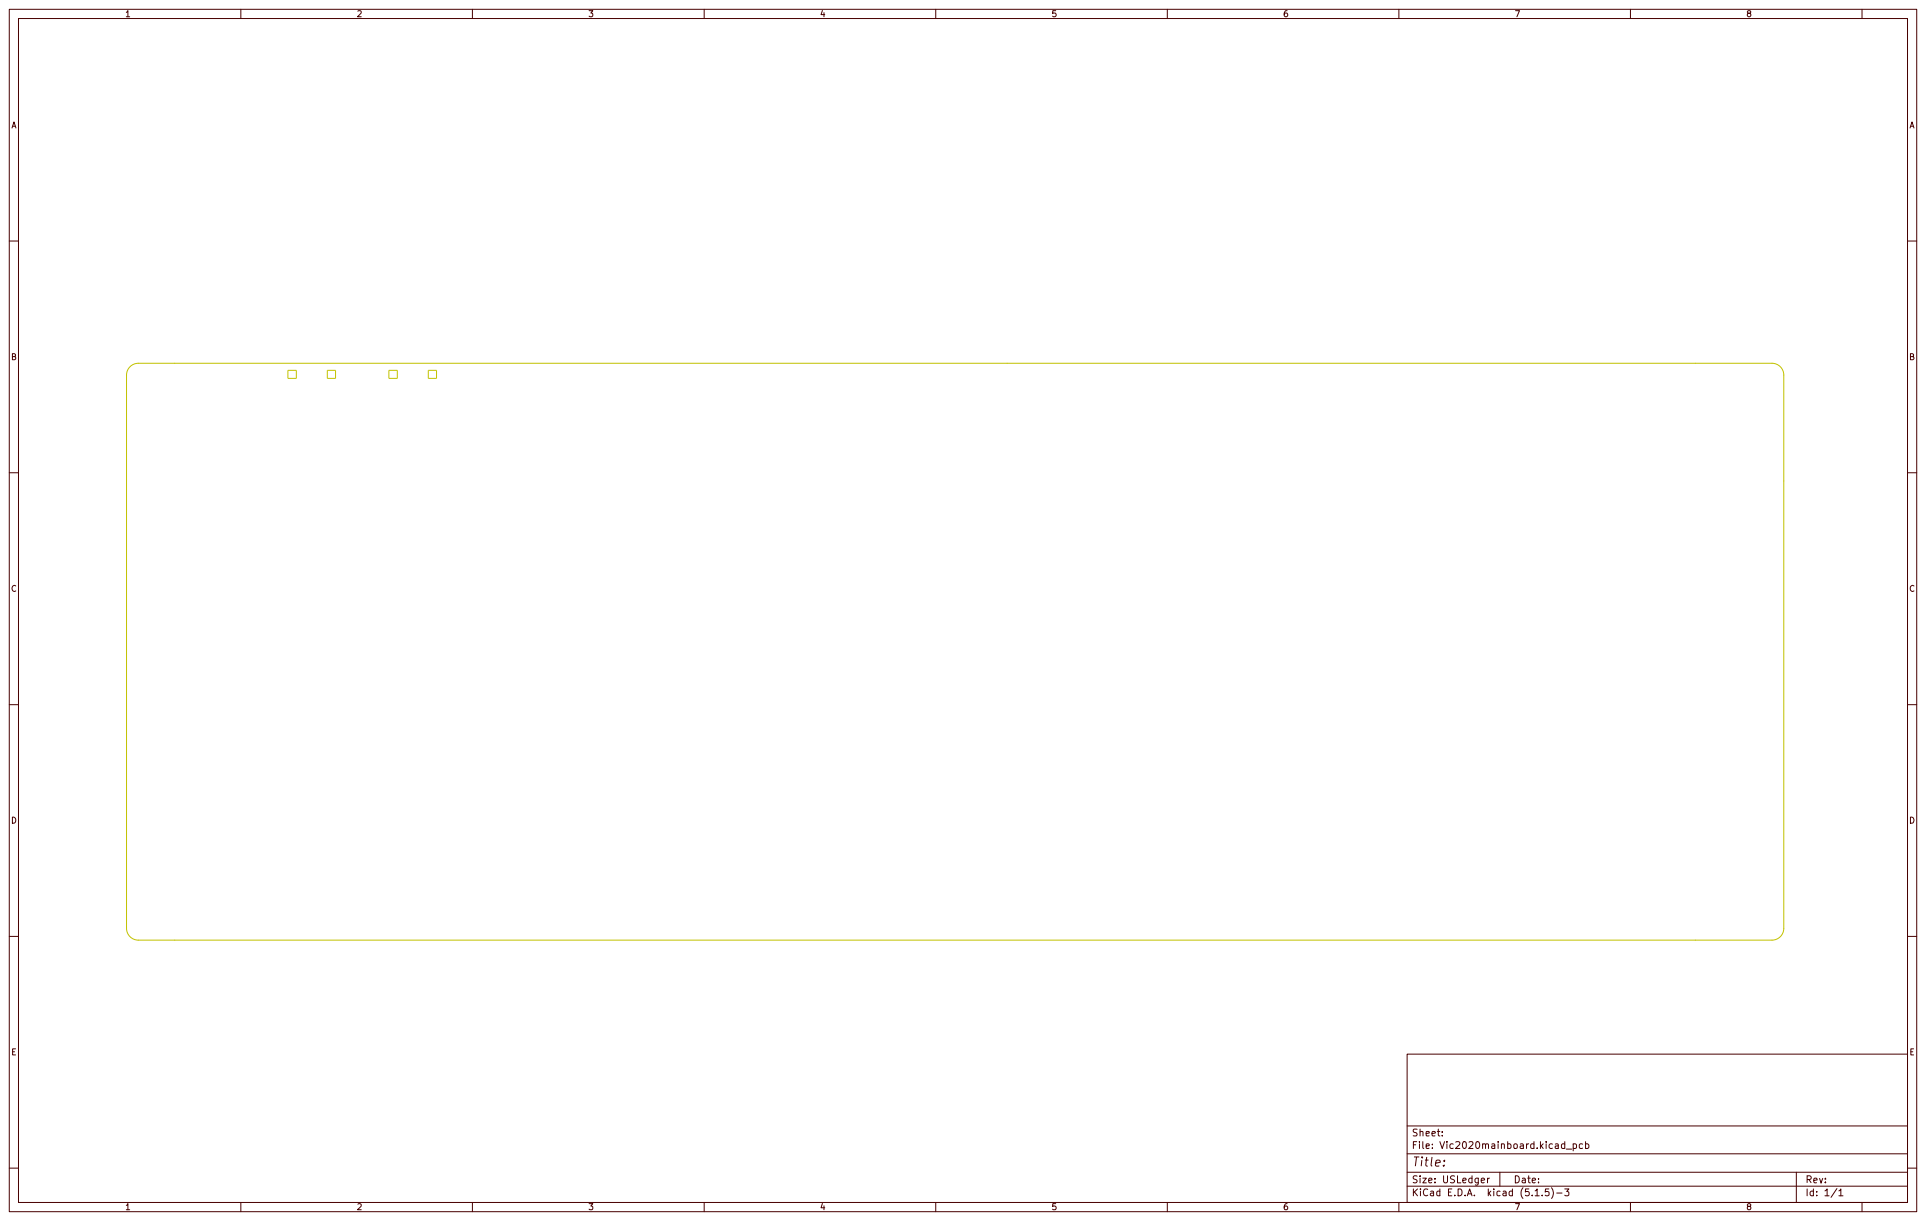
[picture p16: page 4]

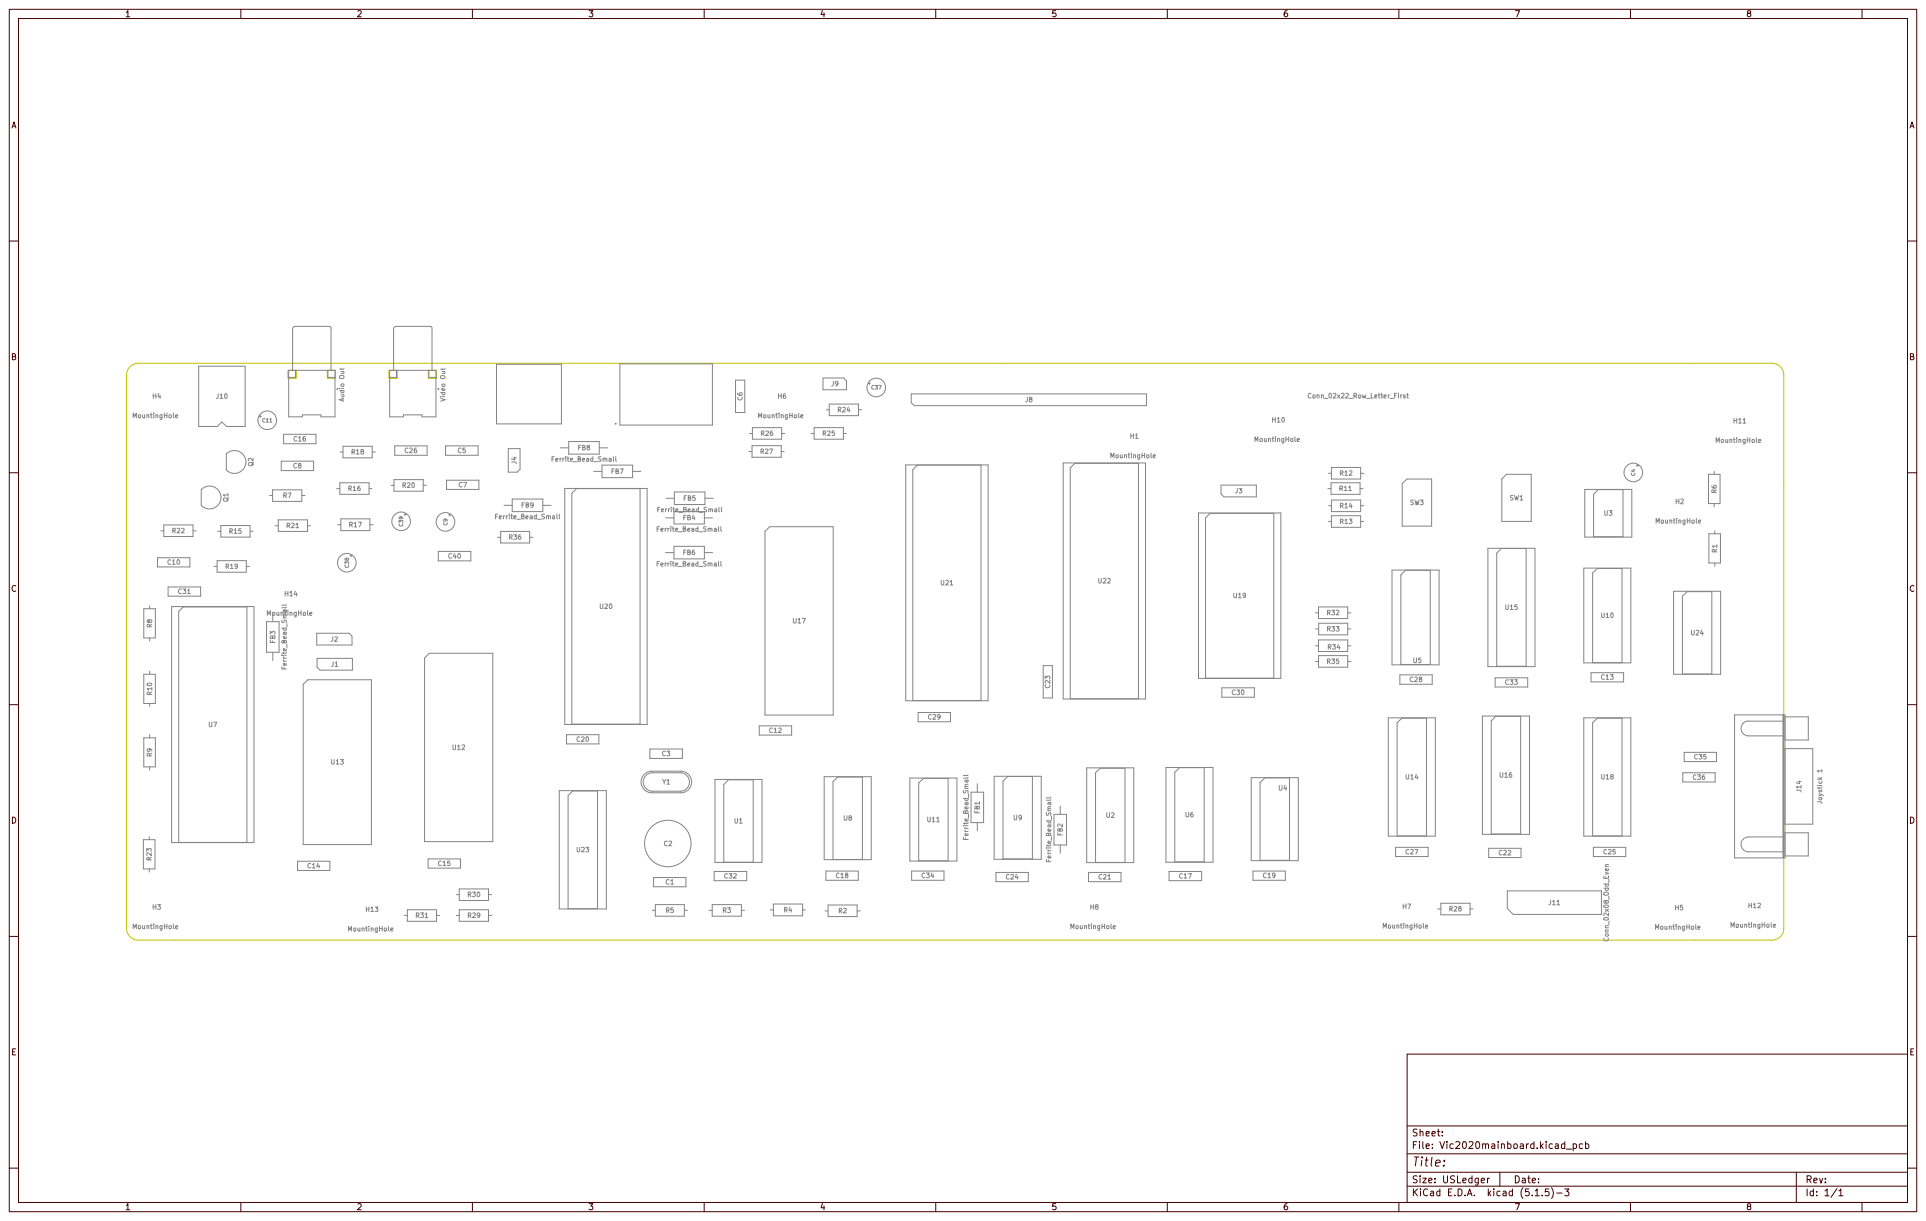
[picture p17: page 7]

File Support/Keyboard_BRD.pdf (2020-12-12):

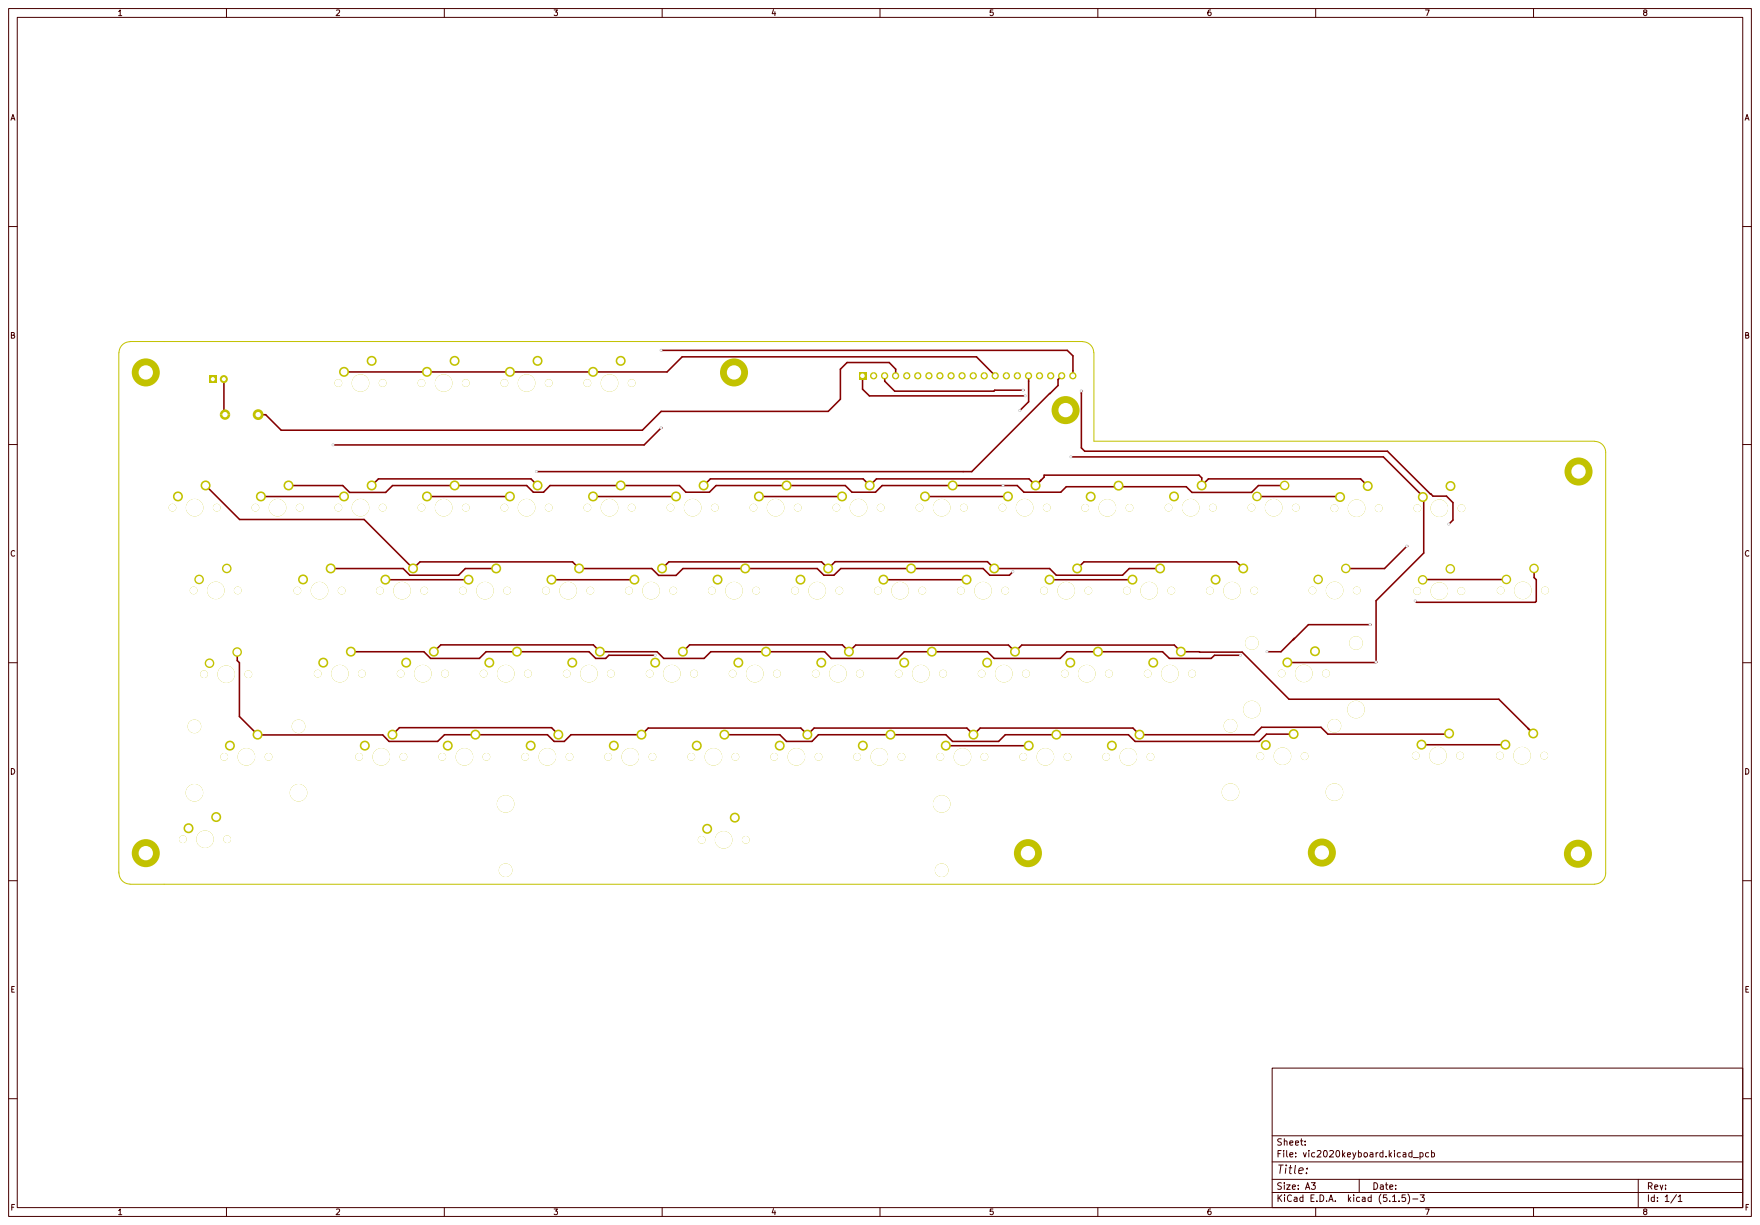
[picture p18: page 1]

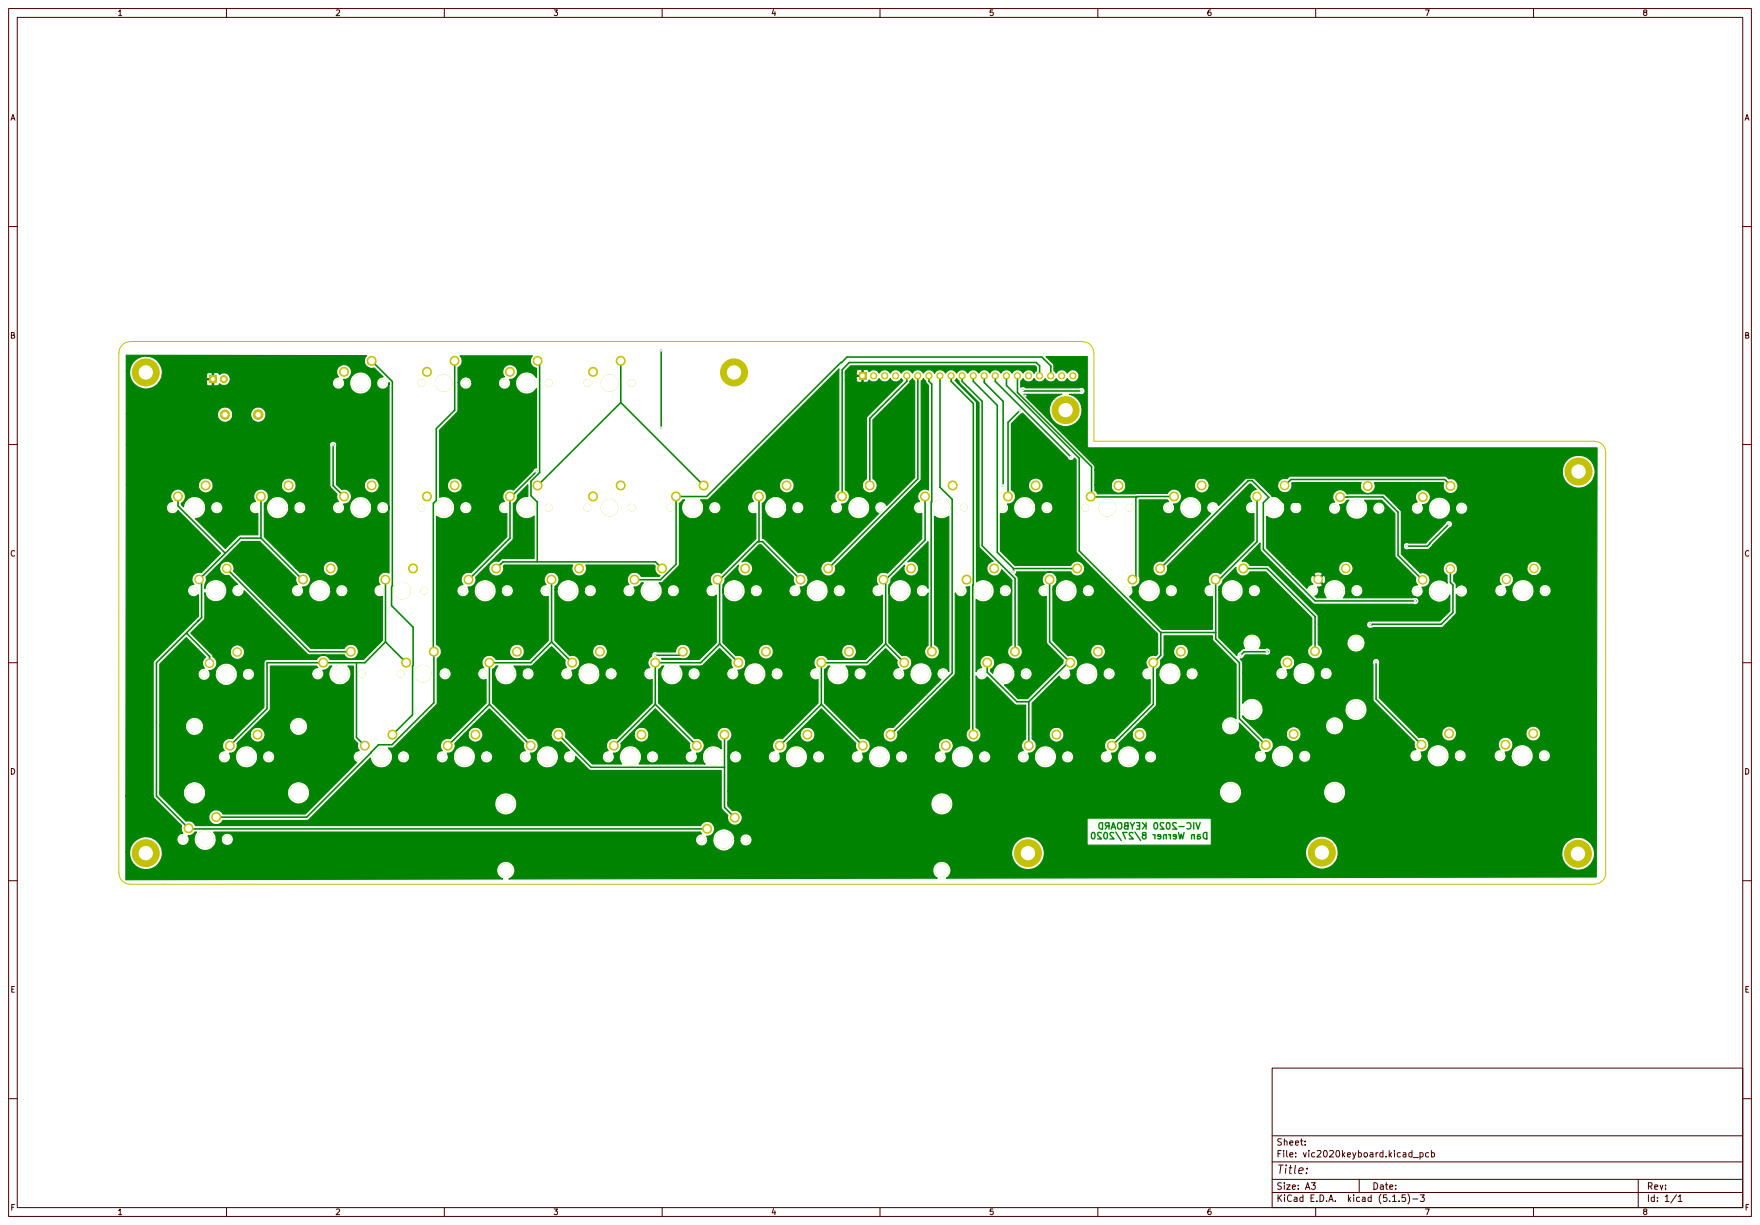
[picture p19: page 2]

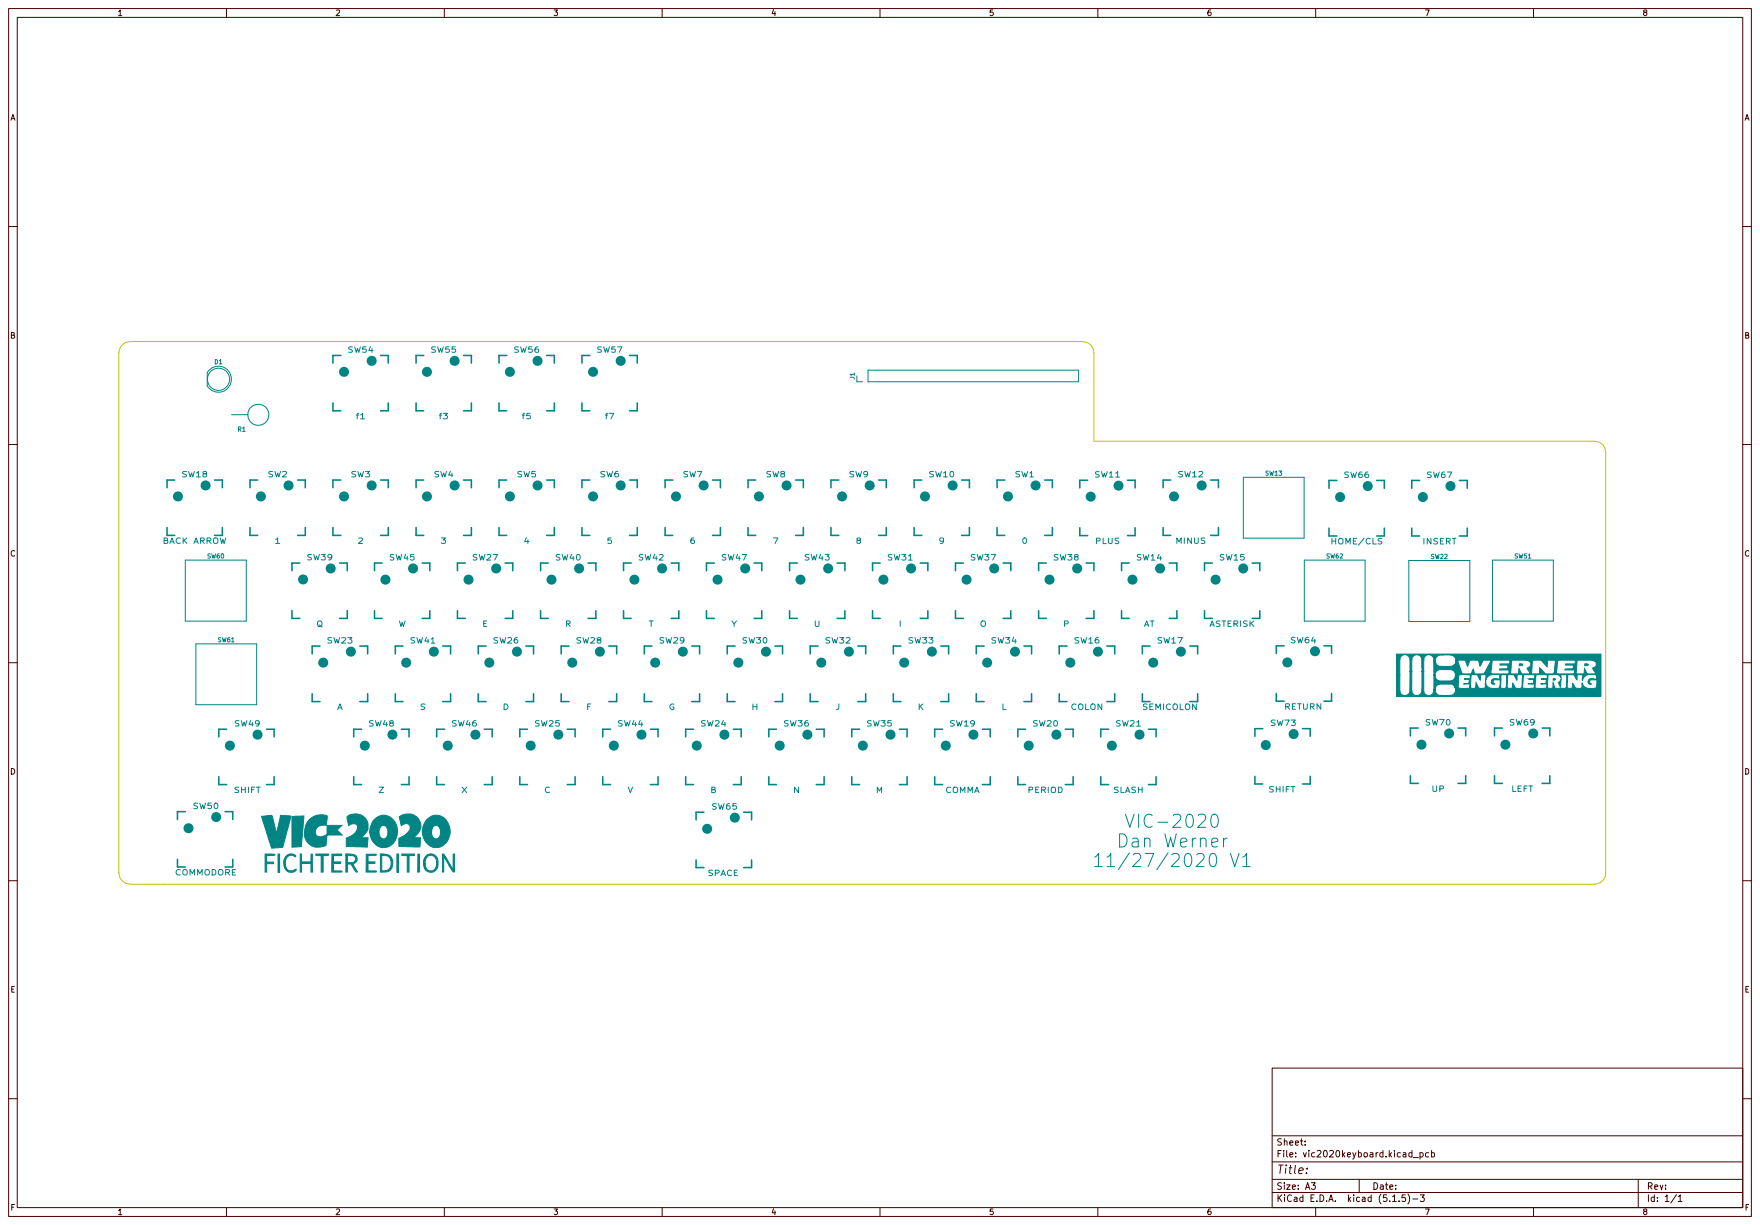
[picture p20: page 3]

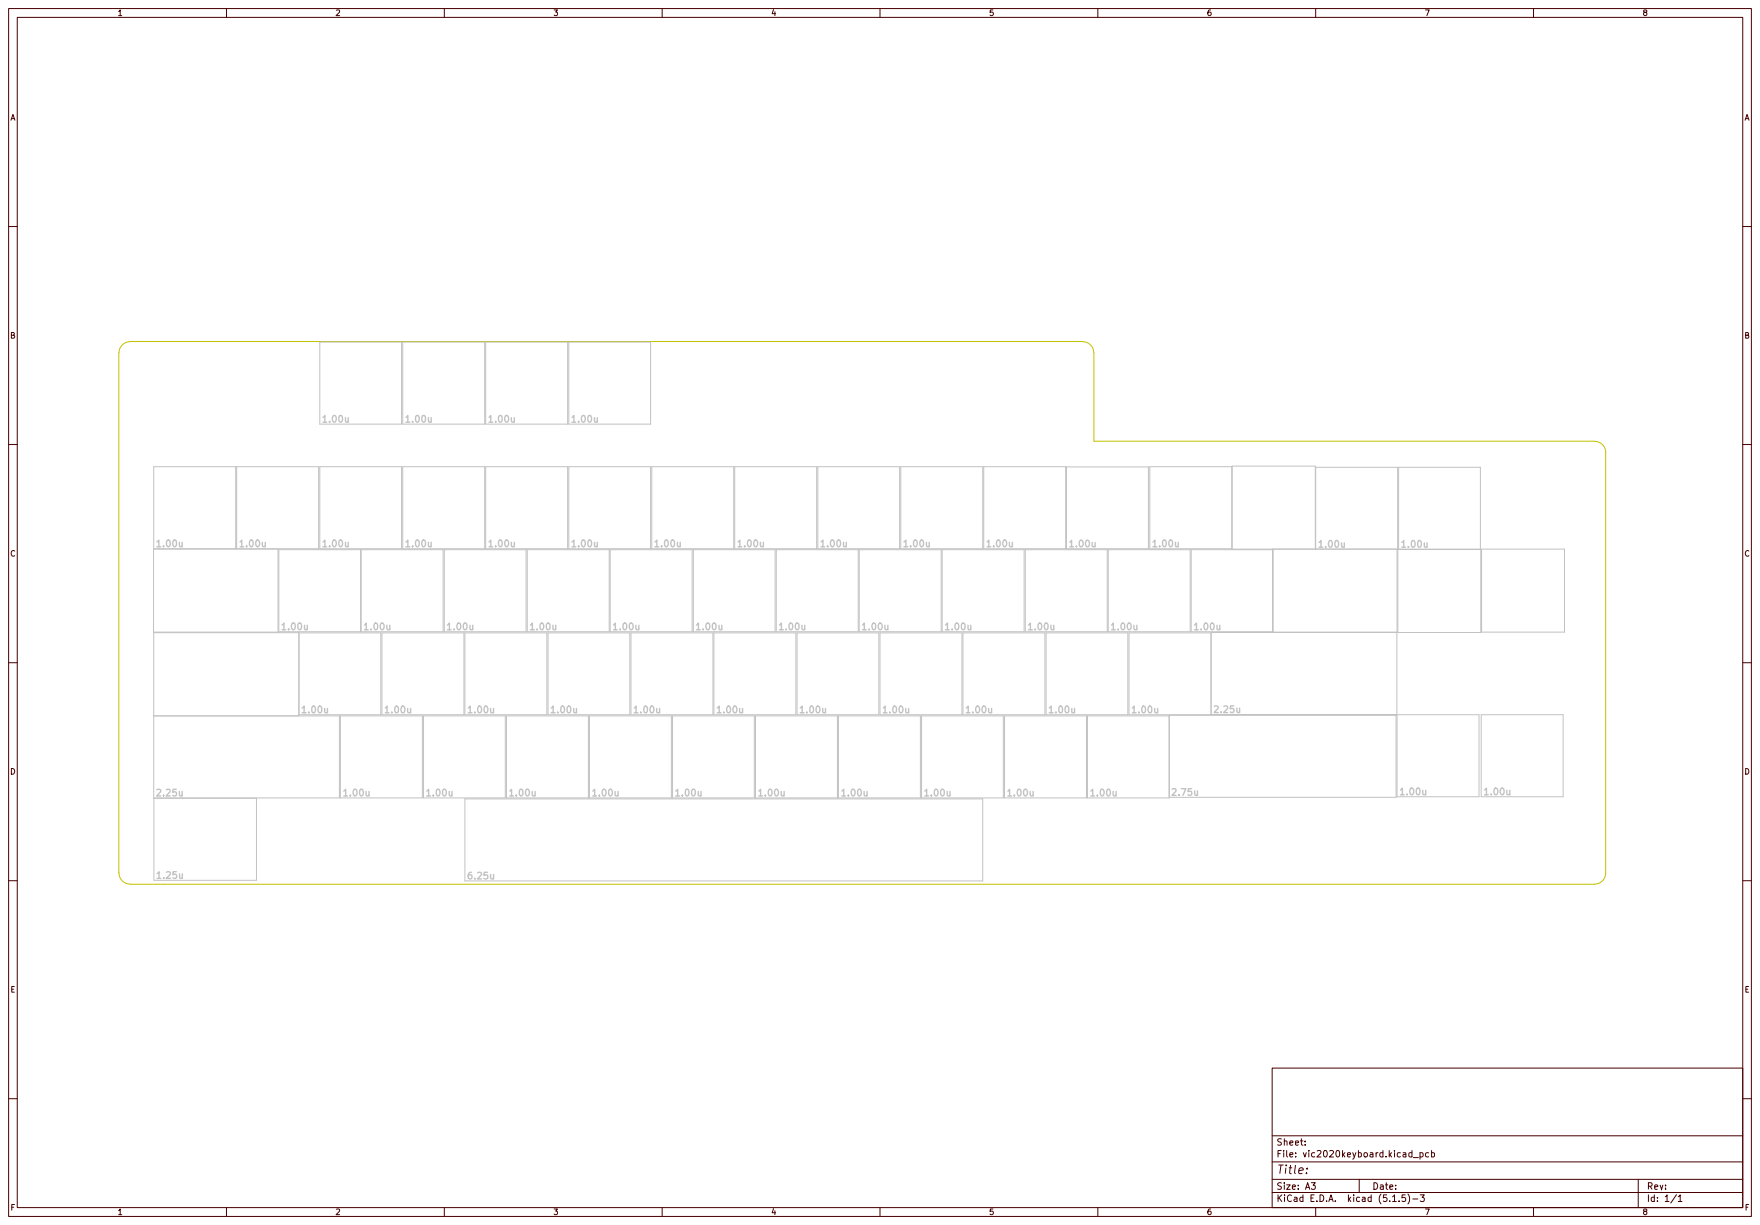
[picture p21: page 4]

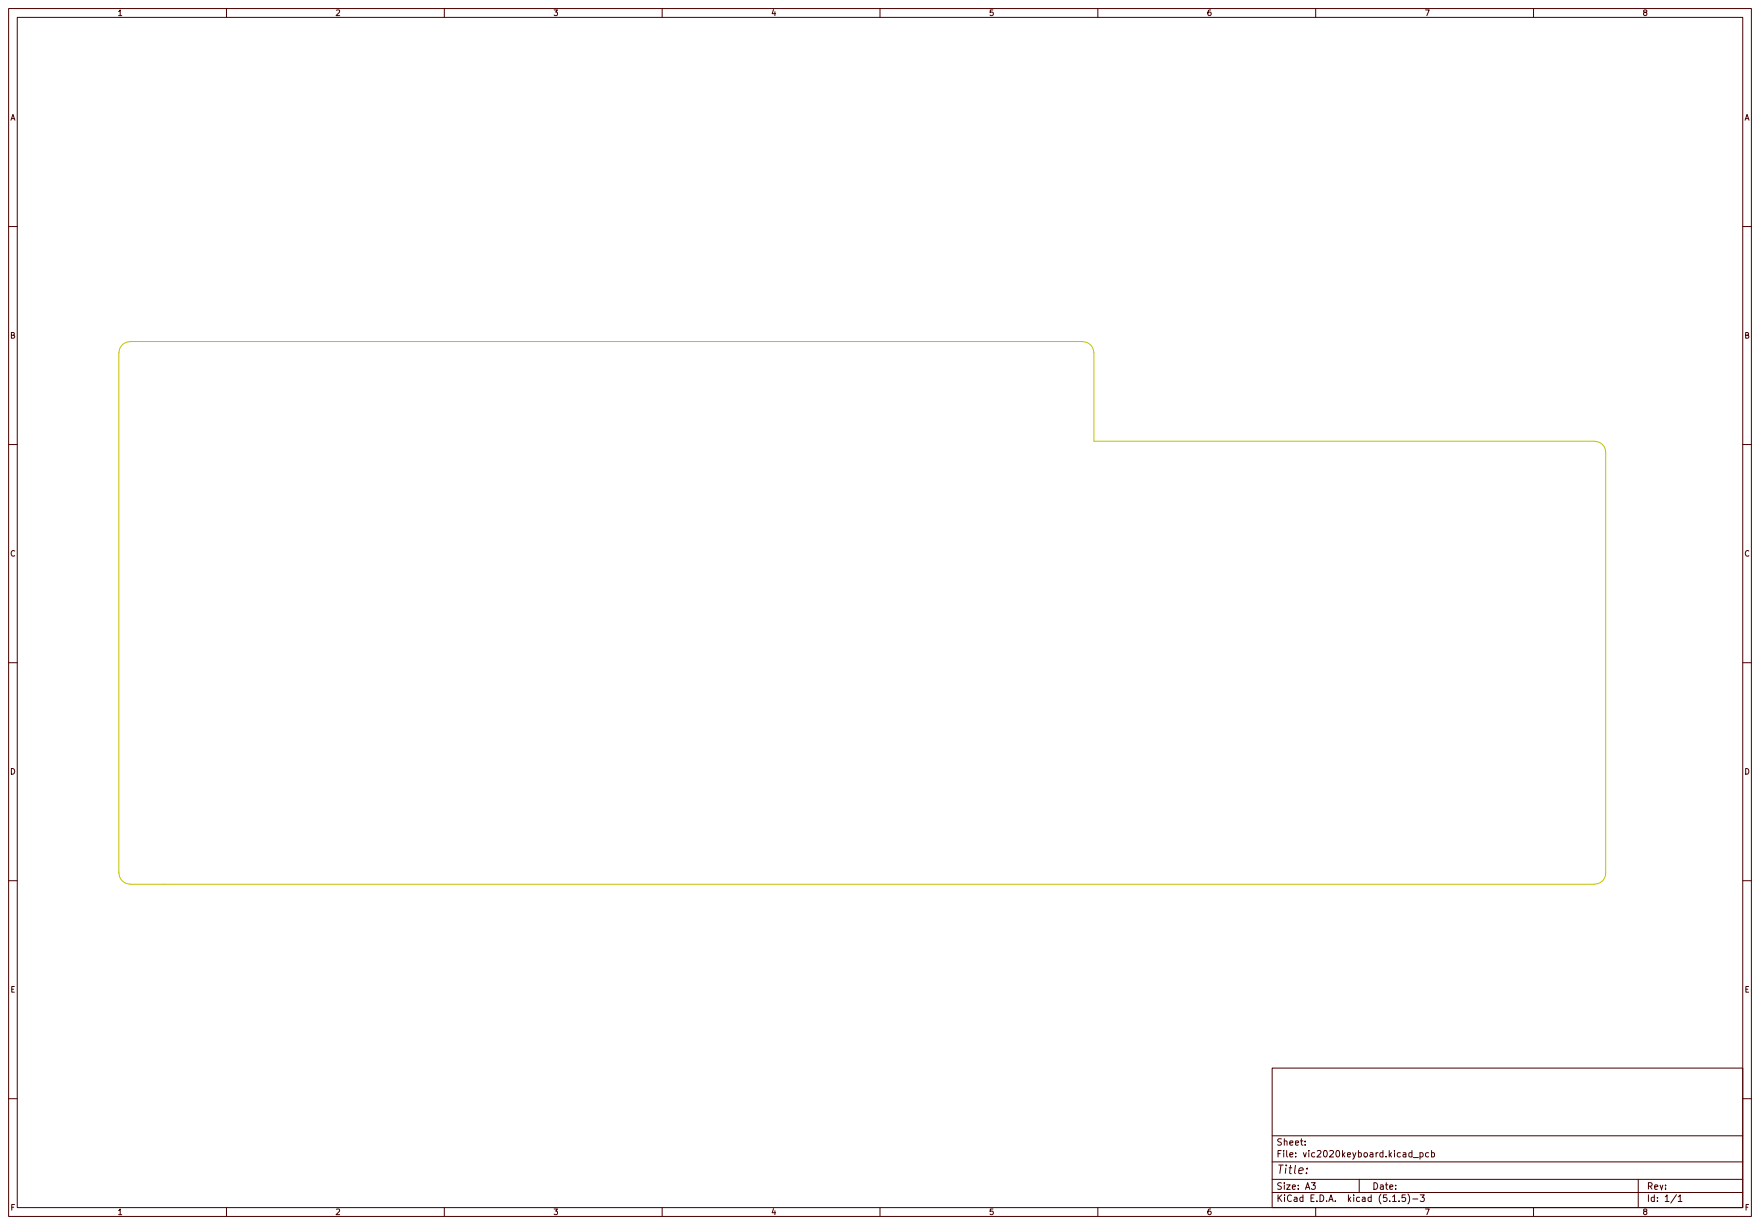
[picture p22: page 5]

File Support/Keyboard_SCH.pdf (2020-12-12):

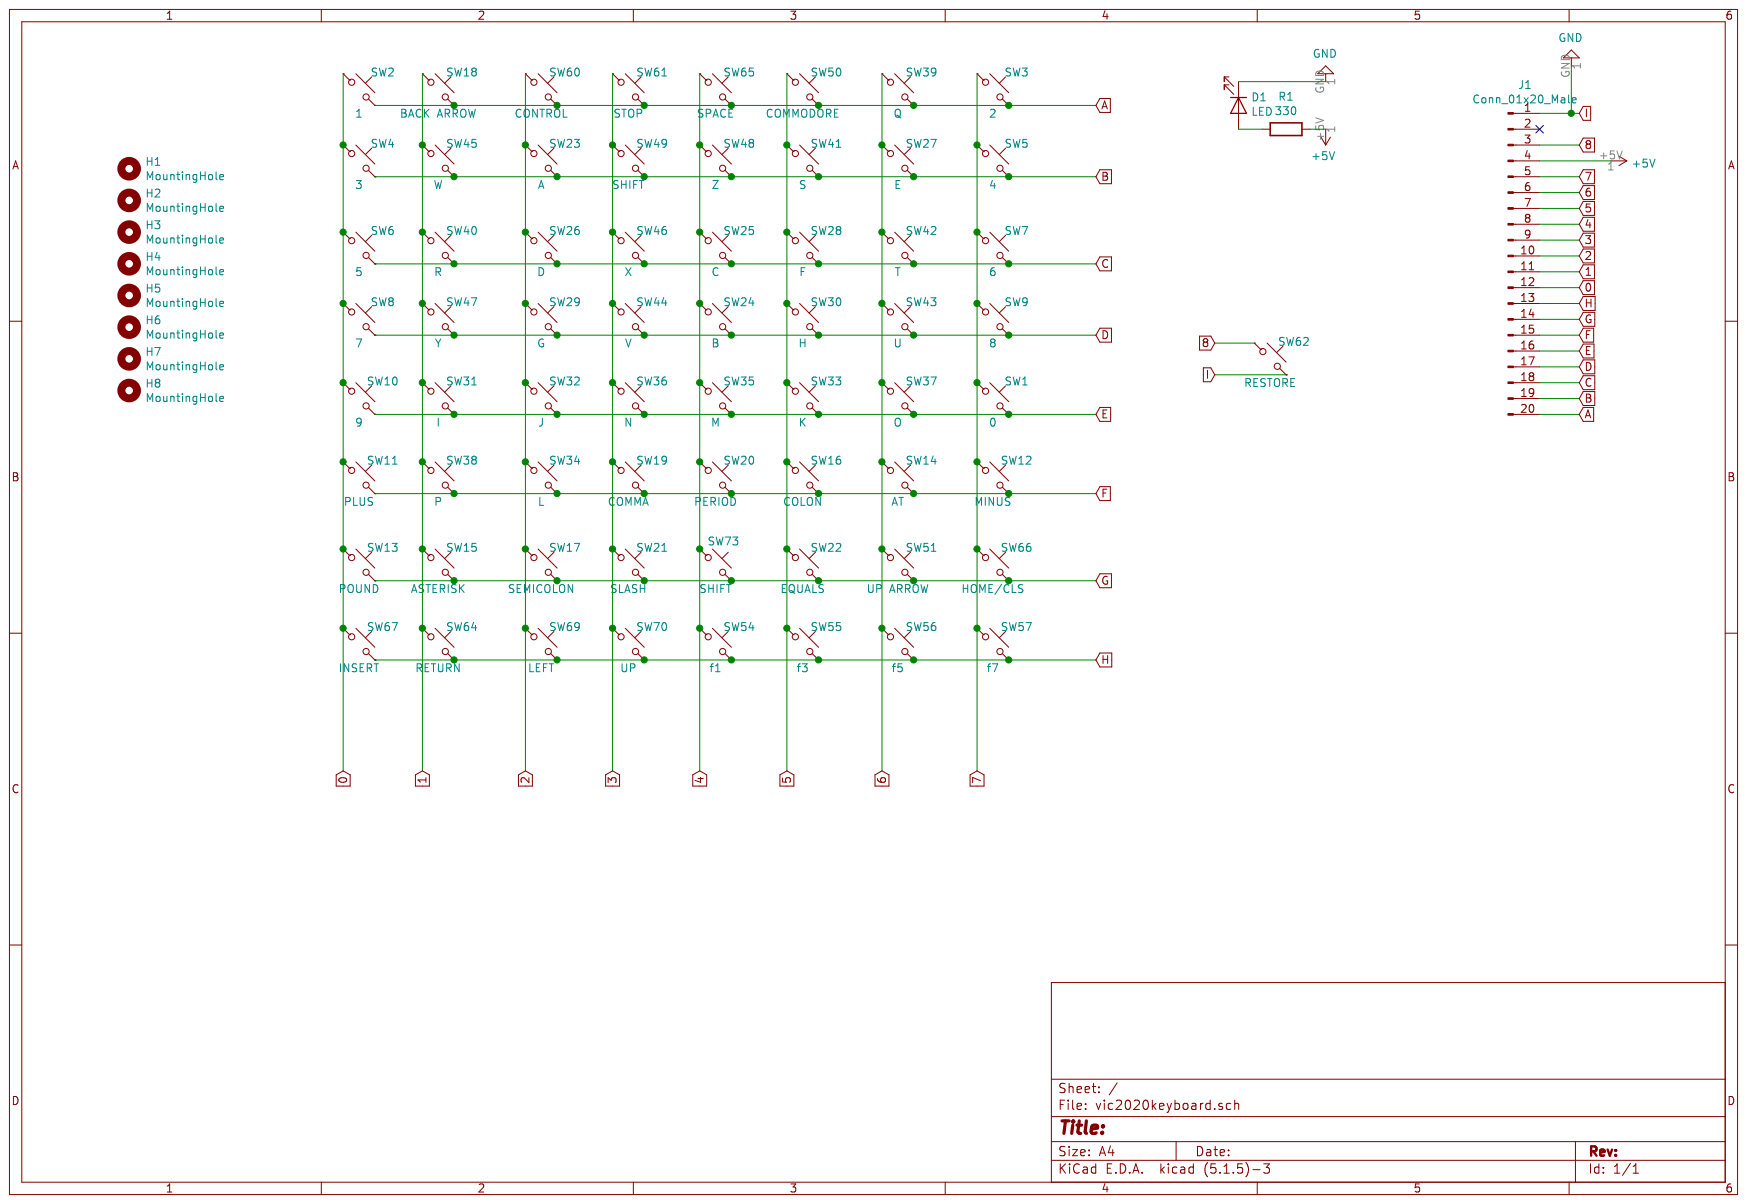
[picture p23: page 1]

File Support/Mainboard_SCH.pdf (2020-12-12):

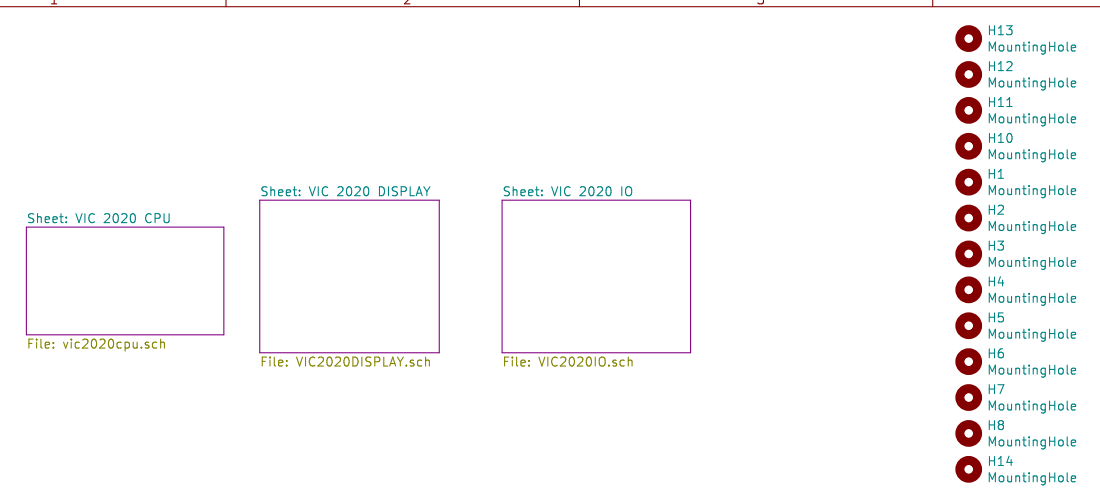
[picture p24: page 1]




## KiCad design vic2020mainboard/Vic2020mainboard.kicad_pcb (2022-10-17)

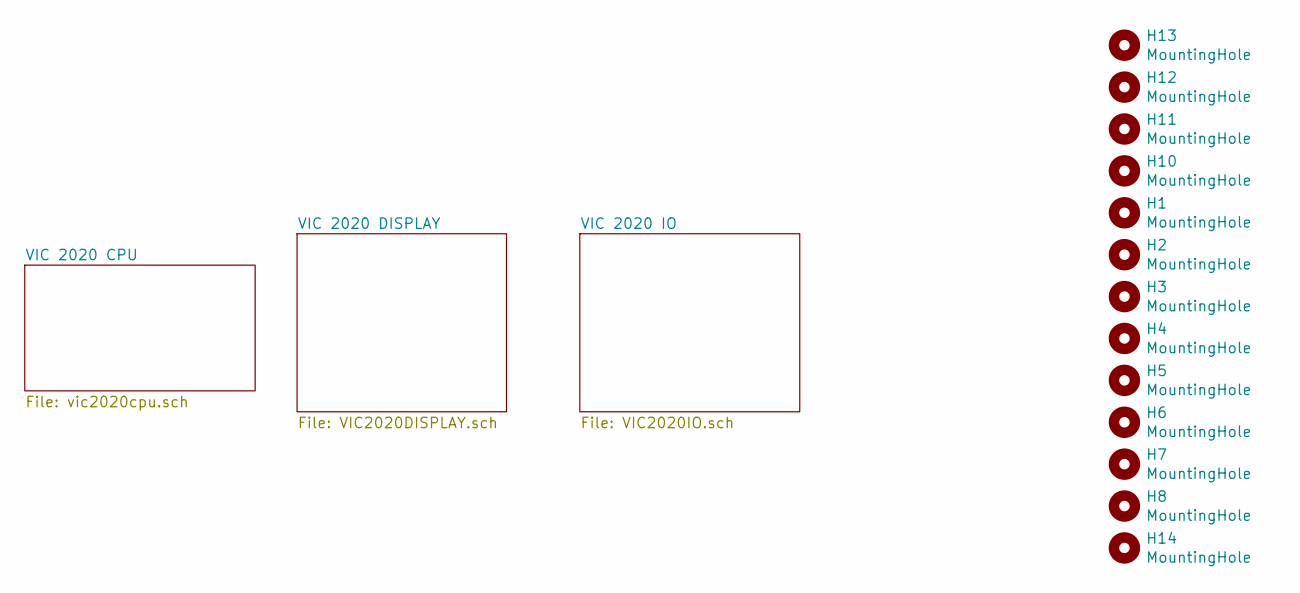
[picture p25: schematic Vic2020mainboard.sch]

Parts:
H1, H2, H3, H4, H5, H6, H7, H8, H10, H11, H12, H13, H14: MountingHole; MountingHole_3.2mm_M3_Pad

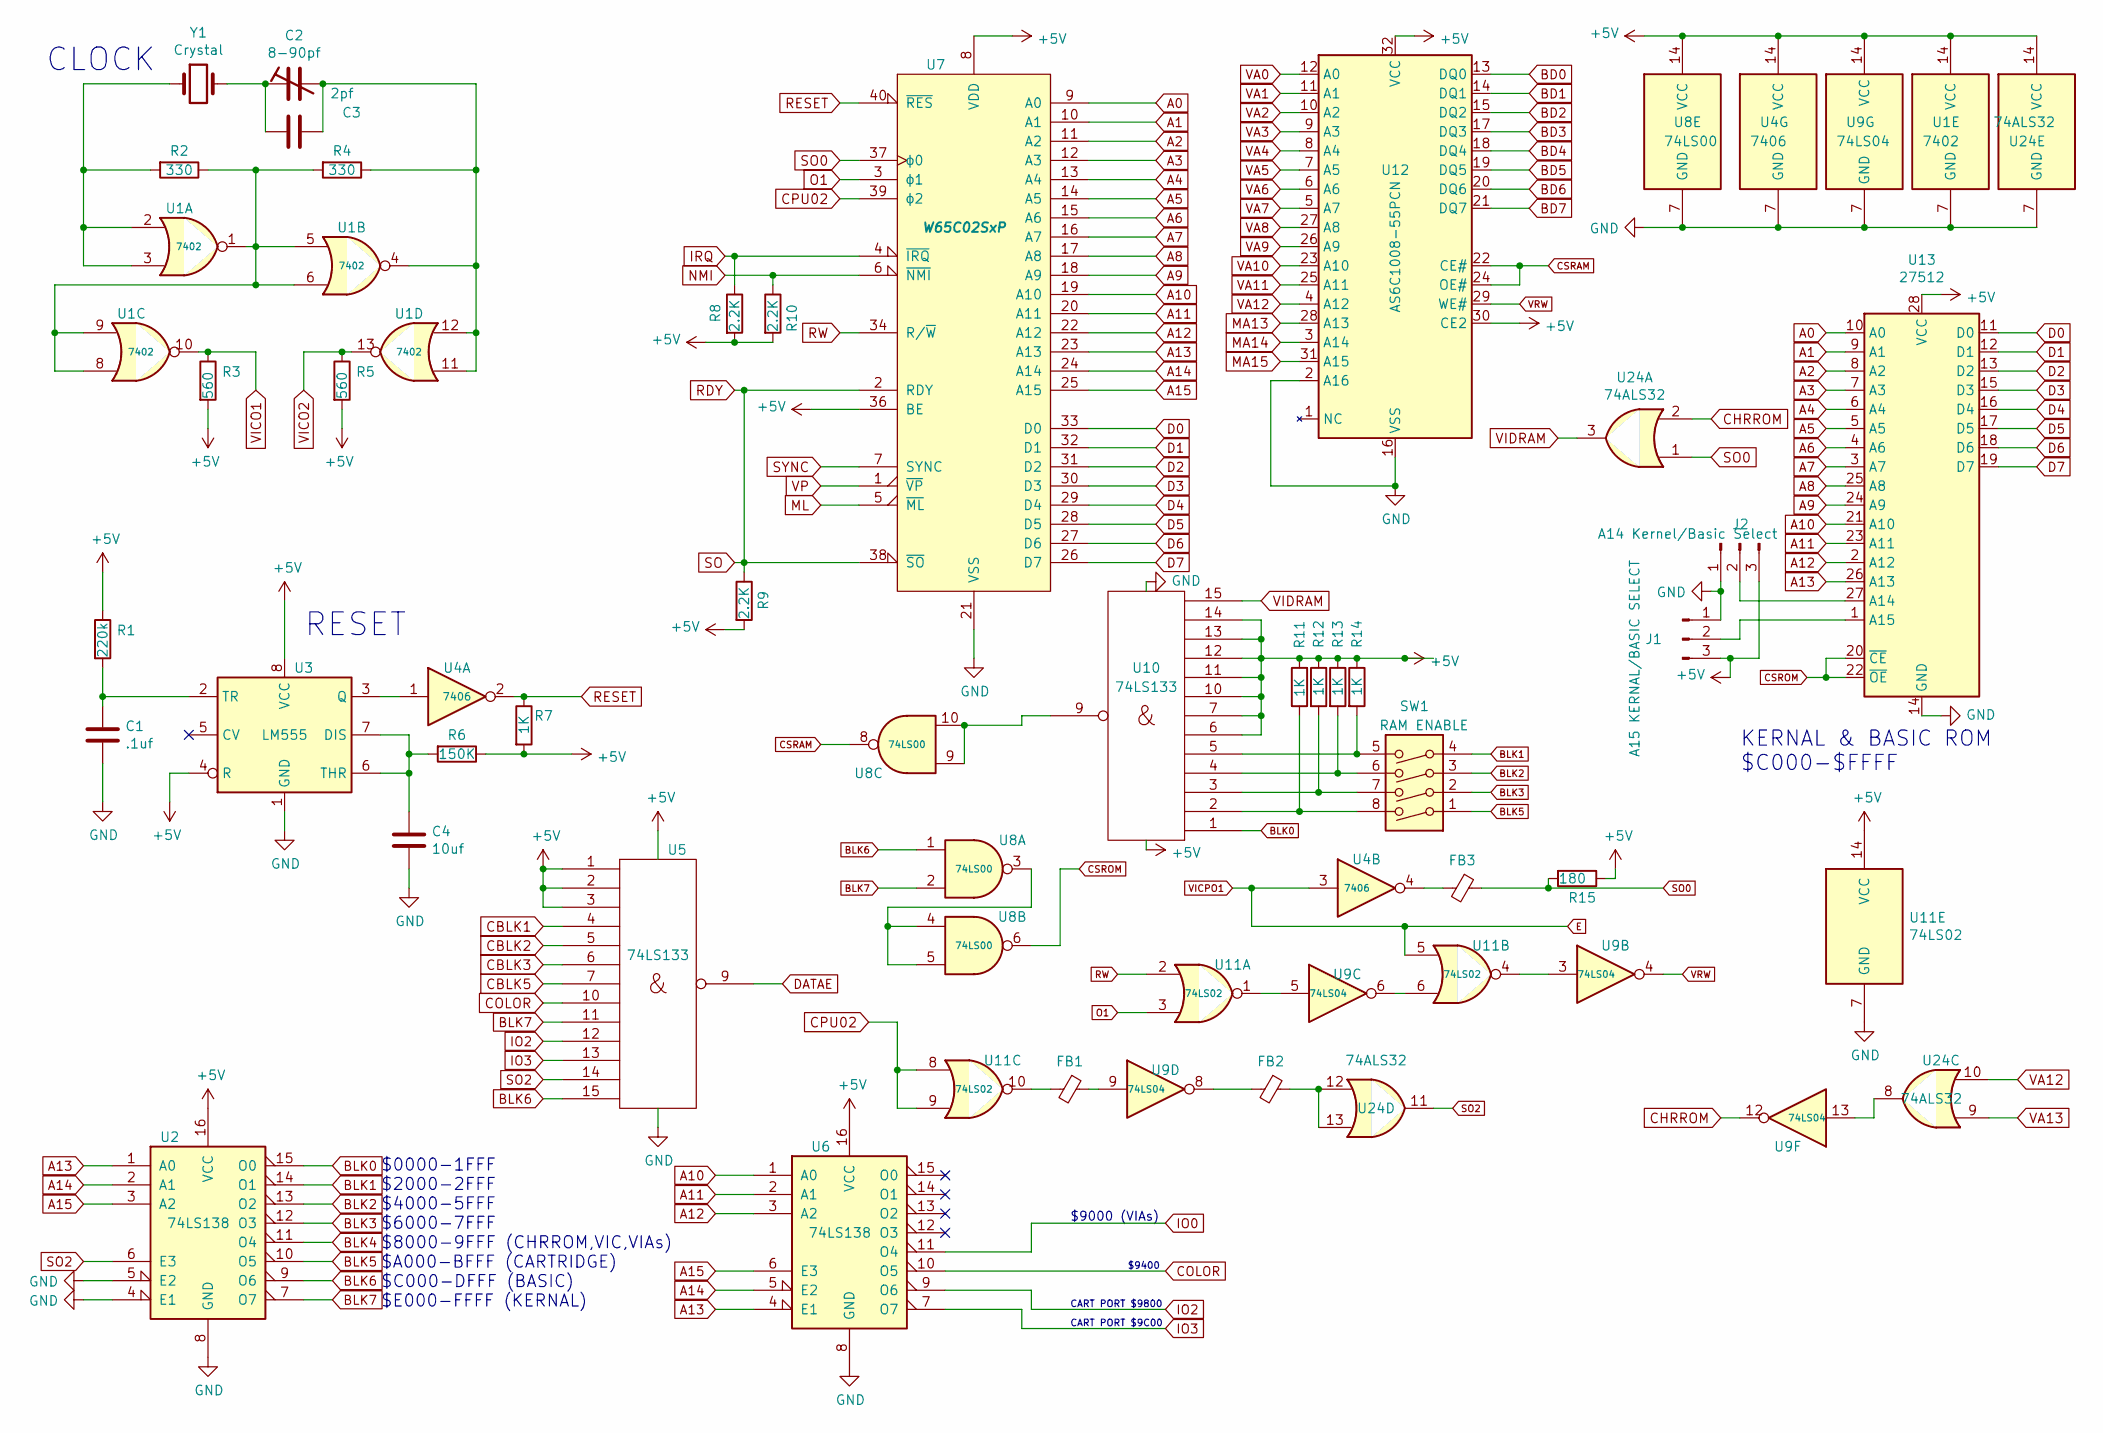
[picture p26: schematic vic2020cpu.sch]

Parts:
C1: .1uf; C_Rect_L7.0mm_W2.0mm_P5.00mm
C2: 8-90pf; C_Radial_D10.0mm_H12.5mm_P5.00mm
C3: 2pf; C_Rect_L7.0mm_W2.0mm_P5.00mm
C4: 10uf; CP_Radial_D4.0mm_P2.00mm
FB1, FB2, FB3: Ferrite_Bead_Small; L_Axial_L6.6mm_D2.7mm_P10.16mm_Horizontal_Vishay_IM-2
J1: A15 KERNAL/BASIC SELECT; PinHeader_1x03_P2.54mm_Vertical
J2: A14 Kernel/Basic Select; PinHeader_1x03_P2.54mm_Vertical
R1: 220k; R_Axial_DIN0207_L6.3mm_D2.5mm_P7.62mm_Horizontal
R2, R4: 330; R_Axial_DIN0207_L6.3mm_D2.5mm_P7.62mm_Horizontal
R3, R5: 560; R_Axial_DIN0207_L6.3mm_D2.5mm_P7.62mm_Horizontal
R6: 150K; R_Axial_DIN0207_L6.3mm_D2.5mm_P7.62mm_Horizontal
R7, R11, R12, R13, R14: 1K; R_Axial_DIN0207_L6.3mm_D2.5mm_P7.62mm_Horizontal
R8, R9, R10: 2.2K; R_Axial_DIN0207_L6.3mm_D2.5mm_P7.62mm_Horizontal
R15: 180; R_Axial_DIN0207_L6.3mm_D2.5mm_P7.62mm_Horizontal
SW1: RAM ENABLE; DIP-8_W7.62mm
U1: 7402; DIP-14_W7.62mm_Socket
U2, U6: 74LS138; DIP-16_W7.62mm_Socket
U3: LM555; DIP-8_W7.62mm_Socket
U4: 7406; DIP-14_W7.62mm_Socket
U5, U10: 74LS133; DIP-16_W7.62mm_Socket
U7: W65C02SxP; DIP-40_W15.24mm_Socket
U8: 74LS00; DIP-14_W7.62mm_Socket
U9: 74LS04; DIP-14_W7.62mm_Socket
U11: 74LS02; DIP-14_W7.62mm_Socket
U12: AS6C1008-55PCN; DIP-32_W15.24mm
U13: 27512; DIP-28_W15.24mm
U24: 74ALS32; DIP-14_W7.62mm_Socket
Y1: Crystal; Crystal_HC18-U_Vertical

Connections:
A0: U7.9 (A0), U13.10 (A0); also elsewhere on the board
A1: U7.10 (A1), U13.9 (A1); also elsewhere on the board
A2: U7.11 (A2), U13.8 (A2); also elsewhere on the board
A3: U7.12 (A3), U13.7 (A3); also elsewhere on the board
A4: U7.13 (A4), U13.6 (A4); also elsewhere on the board
A5: U7.14 (A5), U13.5 (A5); also elsewhere on the board
A6: U7.15 (A6), U13.4 (A6); also elsewhere on the board
A7: U7.16 (A7), U13.3 (A7); also elsewhere on the board
A8: U7.17 (A8), U13.25 (A8); also elsewhere on the board
A9: U7.18 (A9), U13.24 (A9); also elsewhere on the board
A10: U6.1 (A0), U7.19 (A10), U13.21 (A10); also elsewhere on the board
A11: U6.2 (A1), U7.20 (A11), U13.23 (A11); also elsewhere on the board
A12: U6.3 (A2), U7.22 (A12), U13.2 (A12); also elsewhere on the board
A13: U2.1 (A0), U6.4 (E1), U7.23 (A13), U13.26 (A13); also elsewhere on the board
A14: U2.2 (A1), U6.5 (E2), U7.24 (A14); also elsewhere on the board
A15: U2.3 (A2), U6.6 (E3), U7.25 (A15); also elsewhere on the board
BD0: U12.13 (DQ0); also elsewhere on the board
BD1: U12.14 (DQ1); also elsewhere on the board
BD2: U12.15 (DQ2); also elsewhere on the board
BD3: U12.17 (DQ3); also elsewhere on the board
BD4: U12.18 (DQ4); also elsewhere on the board
BD5: U12.19 (DQ5); also elsewhere on the board
BD6: U12.20 (DQ6); also elsewhere on the board
BD7: U12.21 (DQ7); also elsewhere on the board
BLK0: U2.15 (O0), U10.1
BLK1: SW1.4, U2.14 (O1); also elsewhere on the board
BLK2: SW1.3, U2.13 (O2); also elsewhere on the board
BLK3: SW1.2, U2.12 (O3); also elsewhere on the board
BLK4: U2.11 (O4); also elsewhere on the board
BLK5: SW1.1, U2.10 (O5); also elsewhere on the board
BLK6: U2.9 (O6), U5.15, U8.1
BLK7: U2.7 (O7), U5.11, U8.2
CBLK1: U5.4; also elsewhere on the board
CBLK2: U5.5; also elsewhere on the board
CBLK3: U5.6; also elsewhere on the board
CBLK5: U5.7; also elsewhere on the board
CHRROM: U9.12, U24.2
COLOR: U5.10, U6.10 (O5); also elsewhere on the board
CPU02: U7.39 (ϕ2), U11.8, U11.9
CSRAM: U8.8, U12.22 (CE#), U12.24 (OE#)
CSROM: U8.6, U13.20 (~CE), U13.22 (~OE)
D0: U7.33 (D0), U13.11 (D0); also elsewhere on the board
D1: U7.32 (D1), U13.12 (D1); also elsewhere on the board
D2: U7.31 (D2), U13.13 (D2); also elsewhere on the board
D3: U7.30 (D3), U13.15 (D3); also elsewhere on the board
D4: U7.29 (D4), U13.16 (D4); also elsewhere on the board
D5: U7.28 (D5), U13.17 (D5); also elsewhere on the board
D6: U7.27 (D6), U13.18 (D6); also elsewhere on the board
D7: U7.26 (D7), U13.19 (D7); also elsewhere on the board
DATAE: U5.9; also elsewhere on the board
E: U4.3, U11.5; also elsewhere on the board
GND: C1.2, C4.2, J1.1, J2.1, U1.7 (GND), U2.4 (E1), U2.5 (E2), U2.8 (GND), U3.1 (GND), U4.7 (GND), U5.8 (Gnd), U6.8 (GND), U7.21 (VSS), U8.7 (GND), U9.7 (GND), U10.8 (Gnd), U11.7 (GND), U12.2 (A16), U12.16 (VSS), U13.14 (GND), U24.7 (GND); also elsewhere on the board
IO0: U6.11 (O4); also elsewhere on the board
IO2: U5.12, U6.9 (O6); also elsewhere on the board
IO3: U5.13, U6.7 (O7); also elsewhere on the board
IRQ: R8.1, U7.4 (~IRQ); also elsewhere on the board
MA13: U12.28 (A13); also elsewhere on the board
MA14: U12.3 (A14); also elsewhere on the board
MA15: U12.31 (A15); also elsewhere on the board
ML: U7.5 (~ML); also elsewhere on the board
NMI: R10.1, U7.6 (~NMI); also elsewhere on the board
unnamed: C1.1, R1.2, U3.2 (TR)
unnamed: C2.1, C3.2, Y1.2
unnamed: C2.2, C3.1, R4.1, U1.4, U1.11, U1.12
unnamed: C4.1, R6.2, U3.6 (THR), U3.7 (DIS)
unnamed: FB1.1, U9.9
unnamed: FB1.2, U11.10
unnamed: FB2.1, U24.12, U24.13
unnamed: FB2.2, U9.8
unnamed: FB3.2, U4.4
unnamed: J1.2, U13.1 (A15)
unnamed: J2.2, U13.27 (A14)
unnamed: R2.1, R4.2, U1.1, U1.5, U1.6, U1.8, U1.9
unnamed: R2.2, U1.2, U1.3, Y1.1
unnamed: R11.1, SW1.8, U10.2
unnamed: R12.2, SW1.7, U10.3
unnamed: R13.2, SW1.6, U10.4
unnamed: R14.2, SW1.5, U10.5
unnamed: U3.3 (Q), U4.1
unnamed: U8.3, U8.4, U8.5
unnamed: U8.9, U8.10, U10.9
unnamed: U9.5, U11.1
unnamed: U9.3, U11.4
unnamed: U9.6, U11.6
unnamed: U9.13, U24.8
O1: U7.3 (ϕ1), U11.3
RDY: R9.1, U7.2 (RDY), U7.38 (~SO); also elsewhere on the board
RESET: R7.1, U4.2, U7.40 (~RES); also elsewhere on the board
RW: U7.34 (R/~W), U11.2; also elsewhere on the board
SO0: FB3.1, R15.2, U7.37 (ϕ0), U24.1
SO2: U2.6 (E3), U5.14, U24.11; also elsewhere on the board
SYNC: U7.7 (SYNC); also elsewhere on the board
VA0: U12.12 (A0); also elsewhere on the board
VA1: U12.11 (A1); also elsewhere on the board
VA2: U12.10 (A2); also elsewhere on the board
VA3: U12.9 (A3); also elsewhere on the board
VA4: U12.8 (A4); also elsewhere on the board
VA5: U12.7 (A5); also elsewhere on the board
VA6: U12.6 (A6); also elsewhere on the board
VA7: U12.5 (A7); also elsewhere on the board
VA8: U12.27 (A8); also elsewhere on the board
VA9: U12.26 (A9); also elsewhere on the board
VA10: U12.23 (A10); also elsewhere on the board
VA11: U12.25 (A11); also elsewhere on the board
VA12: U12.4 (A12), U24.10; also elsewhere on the board
VA13: U24.9; also elsewhere on the board
VCC: J1.3, J2.3, R1.1, R3.2, R5.2, R6.1, R7.2, R8.2, R9.2, R10.2, R11.2, R12.1, R13.1, R14.1, R15.1, U1.14 (VCC), U2.16 (VCC), U3.4 (R), U3.8 (VCC), U4.14 (VCC), U5.1, U5.2, U5.3, U5.16 (Vcc), U6.16 (VCC), U7.8 (VDD), U7.36 (BE), U8.14 (VCC), U9.14 (VCC), U10.6, U10.7, U10.10, U10.11, U10.12, U10.13, U10.14, U10.16 (Vcc), U11.14 (VCC), U12.30 (CE2), U12.32 (VCC), U13.28 (VCC), U24.14 (VCC); also elsewhere on the board
VICO1: R3.1, U1.10; also elsewhere on the board
VICO2: R5.1, U1.13; also elsewhere on the board
VIDRAM: U10.15, U24.3
VP: U7.1 (~VP); also elsewhere on the board
VRW: U9.4, U12.29 (WE#); also elsewhere on the board

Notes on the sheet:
CLOCK
RESET
$0000-1FFF $2000-2FFF $4000-5FFF $6000-7FFF $8000-9FFF (CHRROM,VIC,VIAs) $A000-BFFF (CARTRIDGE) $C000-DFFF (BASIC) $E000-FFFF (KERNAL)
$9000 (VIAs)
CART PORT $9800
CART PORT $9C00
$9400
KERNAL & BASIC ROM $C000-$FFFF

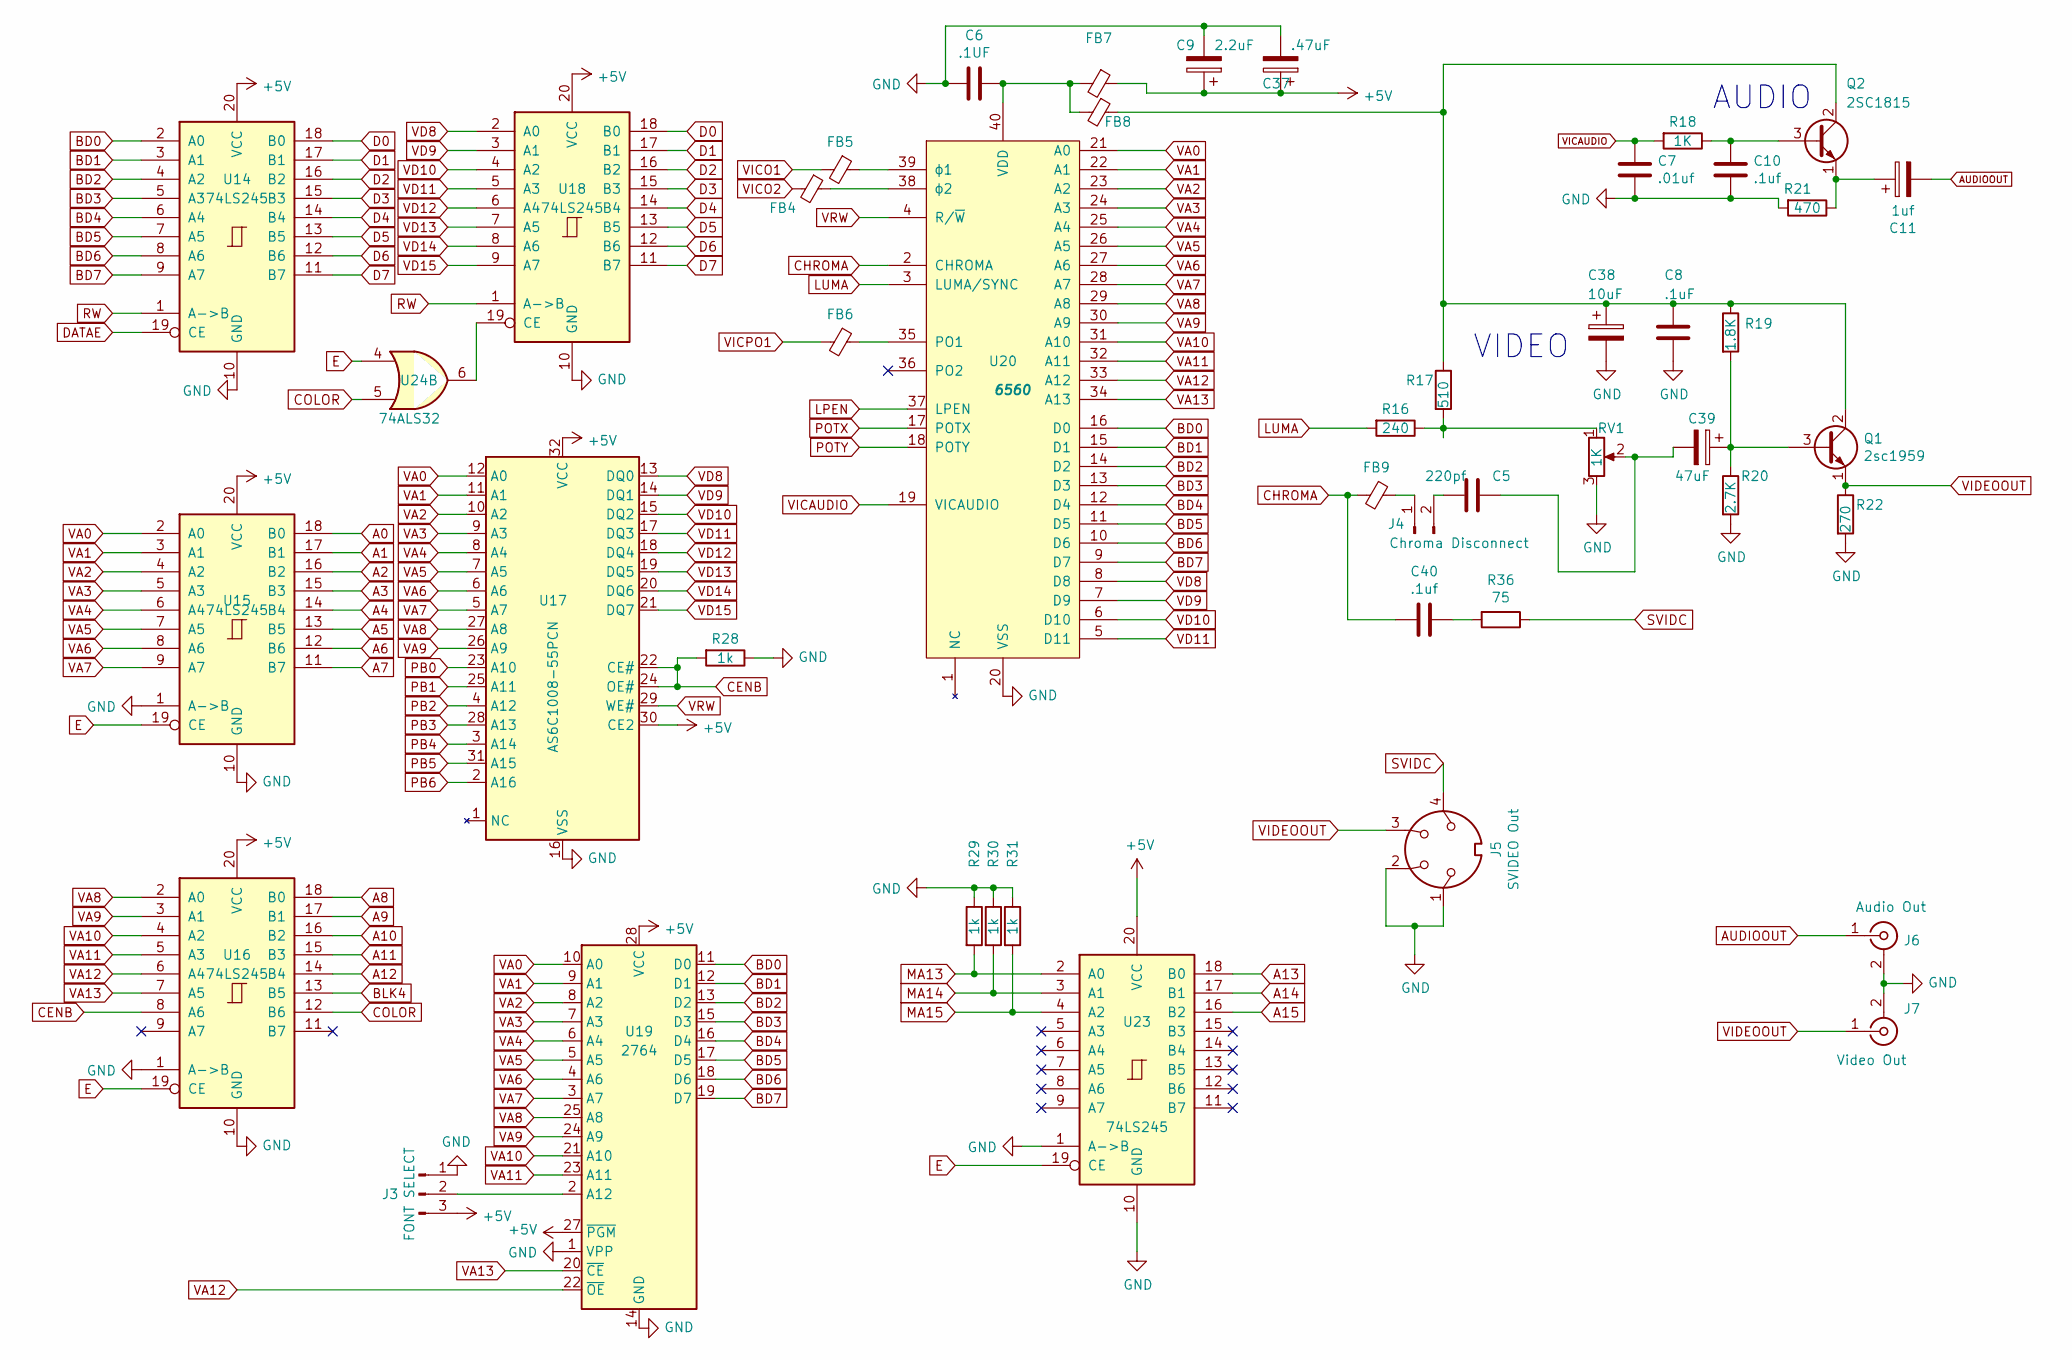
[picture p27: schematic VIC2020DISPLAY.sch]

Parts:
C5: 220pf; C_Rect_L7.0mm_W2.0mm_P5.00mm
C6: .1UF; C_Rect_L7.0mm_W2.0mm_P5.00mm
C7: .01uf; C_Rect_L7.0mm_W2.0mm_P5.00mm
C8: .1uF; C_Rect_L7.0mm_W2.0mm_P5.00mm
C9: 2.2uF; CP_Radial_D4.0mm_P2.00mm
C10, C40: .1uf; C_Rect_L7.0mm_W2.0mm_P5.00mm
C11: 1uf; CP_Radial_D4.0mm_P2.00mm
C37: .47uF; CP_Radial_D4.0mm_P2.00mm
C38: 10uF; CP_Radial_D4.0mm_P2.00mm
C39: 47uF; CP_Radial_D4.0mm_P2.00mm
FB4, FB5, FB6, FB8, FB9: Ferrite_Bead_Small; L_Axial_L6.6mm_D2.7mm_P10.16mm_Horizontal_Vishay_IM-2
FB7: L_Axial_L6.6mm_D2.7mm_P10.16mm_Horizontal_Vishay_IM-2
J3: FONT SELECT; PinHeader_1x03_P2.54mm_Vertical
J4: Chroma Disconnect; PinHeader_1x02_P2.54mm_Vertical
J5: SVIDEO Out; DIN-4TE_5749181-1
J6: Audio Out; CUI_RCJ-041-reversepins
J7: Video Out; CUI_RCJ-041-reversepins
Q1: 2sc1959; TO-92_Inline_Wide
Q2: 2SC1815; TO-92_Inline_Wide
R16: 240; R_Axial_DIN0207_L6.3mm_D2.5mm_P7.62mm_Horizontal
R17: 510; R_Axial_DIN0207_L6.3mm_D2.5mm_P7.62mm_Horizontal
R18: 1K; R_Axial_DIN0207_L6.3mm_D2.5mm_P7.62mm_Horizontal
R19: 1.8K; R_Axial_DIN0207_L6.3mm_D2.5mm_P7.62mm_Horizontal
R20: 2.7K; R_Axial_DIN0207_L6.3mm_D2.5mm_P7.62mm_Horizontal
R21: 470; R_Axial_DIN0207_L6.3mm_D2.5mm_P7.62mm_Horizontal
R22: 270; R_Axial_DIN0207_L6.3mm_D2.5mm_P7.62mm_Horizontal
R28, R29, R30, R31: 1k; R_Axial_DIN0207_L6.3mm_D2.5mm_P7.62mm_Horizontal
R36: 75; R_Axial_DIN0207_L6.3mm_D2.5mm_P7.62mm_Horizontal
RV1: 1K; Potentiometer_Trimmer_2x4.kicad_mod
U14, U15, U16, U18, U23: 74LS245; DIP-20_W7.62mm_Socket
U17: AS6C1008-55PCN; DIP-32_W15.24mm
U19: 2764; DIP-28_W15.24mm_Socket
U20: 6560; DIP-40_W15.24mm_Socket
U24: 74ALS32; DIP-14_W7.62mm_Socket

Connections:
A0: U15.18 (B0); also elsewhere on the board
A1: U15.17 (B1); also elsewhere on the board
A2: U15.16 (B2); also elsewhere on the board
A3: U15.15 (B3); also elsewhere on the board
A4: U15.14 (B4); also elsewhere on the board
A5: U15.13 (B5); also elsewhere on the board
A6: U15.12 (B6); also elsewhere on the board
A7: U15.11 (B7); also elsewhere on the board
A8: U16.18 (B0); also elsewhere on the board
A9: U16.17 (B1); also elsewhere on the board
A10: U16.16 (B2); also elsewhere on the board
A11: U16.15 (B3); also elsewhere on the board
A12: U16.14 (B4); also elsewhere on the board
A13: U23.18 (B0); also elsewhere on the board
A14: U23.17 (B1); also elsewhere on the board
A15: U23.16 (B2); also elsewhere on the board
AUDIOOUT: C11.2, J6.1 (In)
BD0: U14.2 (A0), U19.11 (D0), U20.16 (D0); also elsewhere on the board
BD1: U14.3 (A1), U19.12 (D1), U20.15 (D1); also elsewhere on the board
BD2: U14.4 (A2), U19.13 (D2), U20.14 (D2); also elsewhere on the board
BD3: U14.5 (A3), U19.15 (D3), U20.13 (D3); also elsewhere on the board
BD4: U14.6 (A4), U19.16 (D4), U20.12 (D4); also elsewhere on the board
BD5: U14.7 (A5), U19.17 (D5), U20.11 (D5); also elsewhere on the board
BD6: U14.8 (A6), U19.18 (D6), U20.10 (D6); also elsewhere on the board
BD7: U14.9 (A7), U19.19 (D7), U20.9 (D7); also elsewhere on the board
BLK4: U16.13 (B5); also elsewhere on the board
CENB: R28.2, U16.8 (A6), U17.22 (CE#), U17.24 (OE#)
CHROMA: C40.2, FB9.2, U20.2 (CHROMA)
COLOR: U16.12 (B6), U24.5; also elsewhere on the board
D0: U14.18 (B0), U18.18 (B0); also elsewhere on the board
D1: U14.17 (B1), U18.17 (B1); also elsewhere on the board
D2: U14.16 (B2), U18.16 (B2); also elsewhere on the board
D3: U14.15 (B3), U18.15 (B3); also elsewhere on the board
D4: U14.14 (B4), U18.14 (B4); also elsewhere on the board
D5: U14.13 (B5), U18.13 (B5); also elsewhere on the board
D6: U14.12 (B6), U18.12 (B6); also elsewhere on the board
D7: U14.11 (B7), U18.11 (B7); also elsewhere on the board
DATAE: U14.19 (CE); also elsewhere on the board
E: FB6.2, U15.19 (CE), U16.19 (CE), U23.19 (CE), U24.4; also elsewhere on the board
GND: C6.2, C7.2, C8.2, C9.2, C10.2, C37.2, C38.2, J3.1, J5.1, J5.2, J6.2 (Ext), J7.2 (Ext), R20.2, R21.2, R22.2, R28.1, R29.1, R30.1, R31.1, RV1.3, U14.10 (GND), U15.1 (A->B), U15.10 (GND), U16.1 (A->B), U16.10 (GND), U17.16 (VSS), U18.10 (GND), U19.1 (VPP), U19.14 (GND), U20.20 (VSS), U23.1 (A->B), U23.10 (GND); also elsewhere on the board
LPEN: U20.37 (LPEN); also elsewhere on the board
LUMA: R16.2, U20.3 (LUMA/SYNC)
MA13: R29.2, U23.2 (A0); also elsewhere on the board
MA14: R30.2, U23.3 (A1); also elsewhere on the board
MA15: R31.2, U23.4 (A2); also elsewhere on the board
unnamed: C5.2, J4.2
unnamed: C6.1, FB7.2, FB8.2, U20.40 (VDD)
unnamed: C10.1, Q2.3 (B), R18.1
unnamed: C11.1, Q2.1 (E), R21.1
unnamed: C8.1, C38.1, FB8.1, Q1.2 (C), Q2.2 (C), R17.1, R19.1
unnamed: C39.1, Q1.3 (B), R19.2, R20.1
unnamed: C5.1, C39.2, RV1.2
unnamed: C40.1, R36.2
unnamed: FB4.1, U20.38 (ϕ2)
unnamed: FB5.1, U20.39 (ϕ1)
unnamed: FB6.1, U20.35 (PO1)
unnamed: FB9.1, J4.1
unnamed: J3.2, U19.2 (A12)
unnamed: R16.1, R17.2, RV1.1
unnamed: U18.19 (CE), U24.6
PB0: U17.23 (A10); also elsewhere on the board
PB1: U17.25 (A11); also elsewhere on the board
PB2: U17.4 (A12); also elsewhere on the board
PB3: U17.28 (A13); also elsewhere on the board
PB4: U17.3 (A14); also elsewhere on the board
PB5: U17.31 (A15); also elsewhere on the board
PB6: U17.2 (A16); also elsewhere on the board
POTX: U20.17 (POTX); also elsewhere on the board
POTY: U20.18 (POTY); also elsewhere on the board
RW: U14.1 (A->B), U18.1 (A->B); also elsewhere on the board
SVIDC: J5.4, R36.1
VA0: U15.2 (A0), U17.12 (A0), U19.10 (A0), U20.21 (A0); also elsewhere on the board
VA1: U15.3 (A1), U17.11 (A1), U19.9 (A1), U20.22 (A1); also elsewhere on the board
VA2: U15.4 (A2), U17.10 (A2), U19.8 (A2), U20.23 (A2); also elsewhere on the board
VA3: U15.5 (A3), U17.9 (A3), U19.7 (A3), U20.24 (A3); also elsewhere on the board
VA4: U15.6 (A4), U17.8 (A4), U19.6 (A4), U20.25 (A4); also elsewhere on the board
VA5: U15.7 (A5), U17.7 (A5), U19.5 (A5), U20.26 (A5); also elsewhere on the board
VA6: U15.8 (A6), U17.6 (A6), U19.4 (A6), U20.27 (A6); also elsewhere on the board
VA7: U15.9 (A7), U17.5 (A7), U19.3 (A7), U20.28 (A7); also elsewhere on the board
VA8: U16.2 (A0), U17.27 (A8), U19.25 (A8), U20.29 (A8); also elsewhere on the board
VA9: U16.3 (A1), U17.26 (A9), U19.24 (A9), U20.30 (A9); also elsewhere on the board
VA10: U16.4 (A2), U19.21 (A10), U20.31 (A10); also elsewhere on the board
VA11: U16.5 (A3), U19.23 (A11), U20.32 (A11); also elsewhere on the board
VA12: U16.6 (A4), U19.22 (~OE), U20.33 (A12); also elsewhere on the board
VA13: U16.7 (A5), U19.20 (~CE), U20.34 (A13); also elsewhere on the board
VCC: C9.1, C37.1, FB7.1, J3.3, U14.20 (VCC), U15.20 (VCC), U16.20 (VCC), U17.30 (CE2), U17.32 (VCC), U18.20 (VCC), U19.27 (~PGM), U19.28 (VCC), U23.20 (VCC); also elsewhere on the board
VD8: U17.13 (DQ0), U18.2 (A0), U20.8 (D8)
VD9: U17.14 (DQ1), U18.3 (A1), U20.7 (D9)
VD10: U17.15 (DQ2), U18.4 (A2), U20.6 (D10)
VD11: U17.17 (DQ3), U18.5 (A3), U20.5 (D11)
VD12: U17.18 (DQ4), U18.6 (A4)
VD13: U17.19 (DQ5), U18.7 (A5)
VD14: U17.20 (DQ6), U18.8 (A6)
VD15: U17.21 (DQ7), U18.9 (A7)
VICAUDIO: C7.1, R18.2, U20.19 (VICAUDIO)
VICO1: FB5.2; also elsewhere on the board
VICO2: FB4.2; also elsewhere on the board
VIDEOOUT: J5.3, J7.1 (In), Q1.1 (E), R22.1
VRW: U17.29 (WE#), U20.4 (R/~W); also elsewhere on the board

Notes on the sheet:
AUDIO
VIDEO

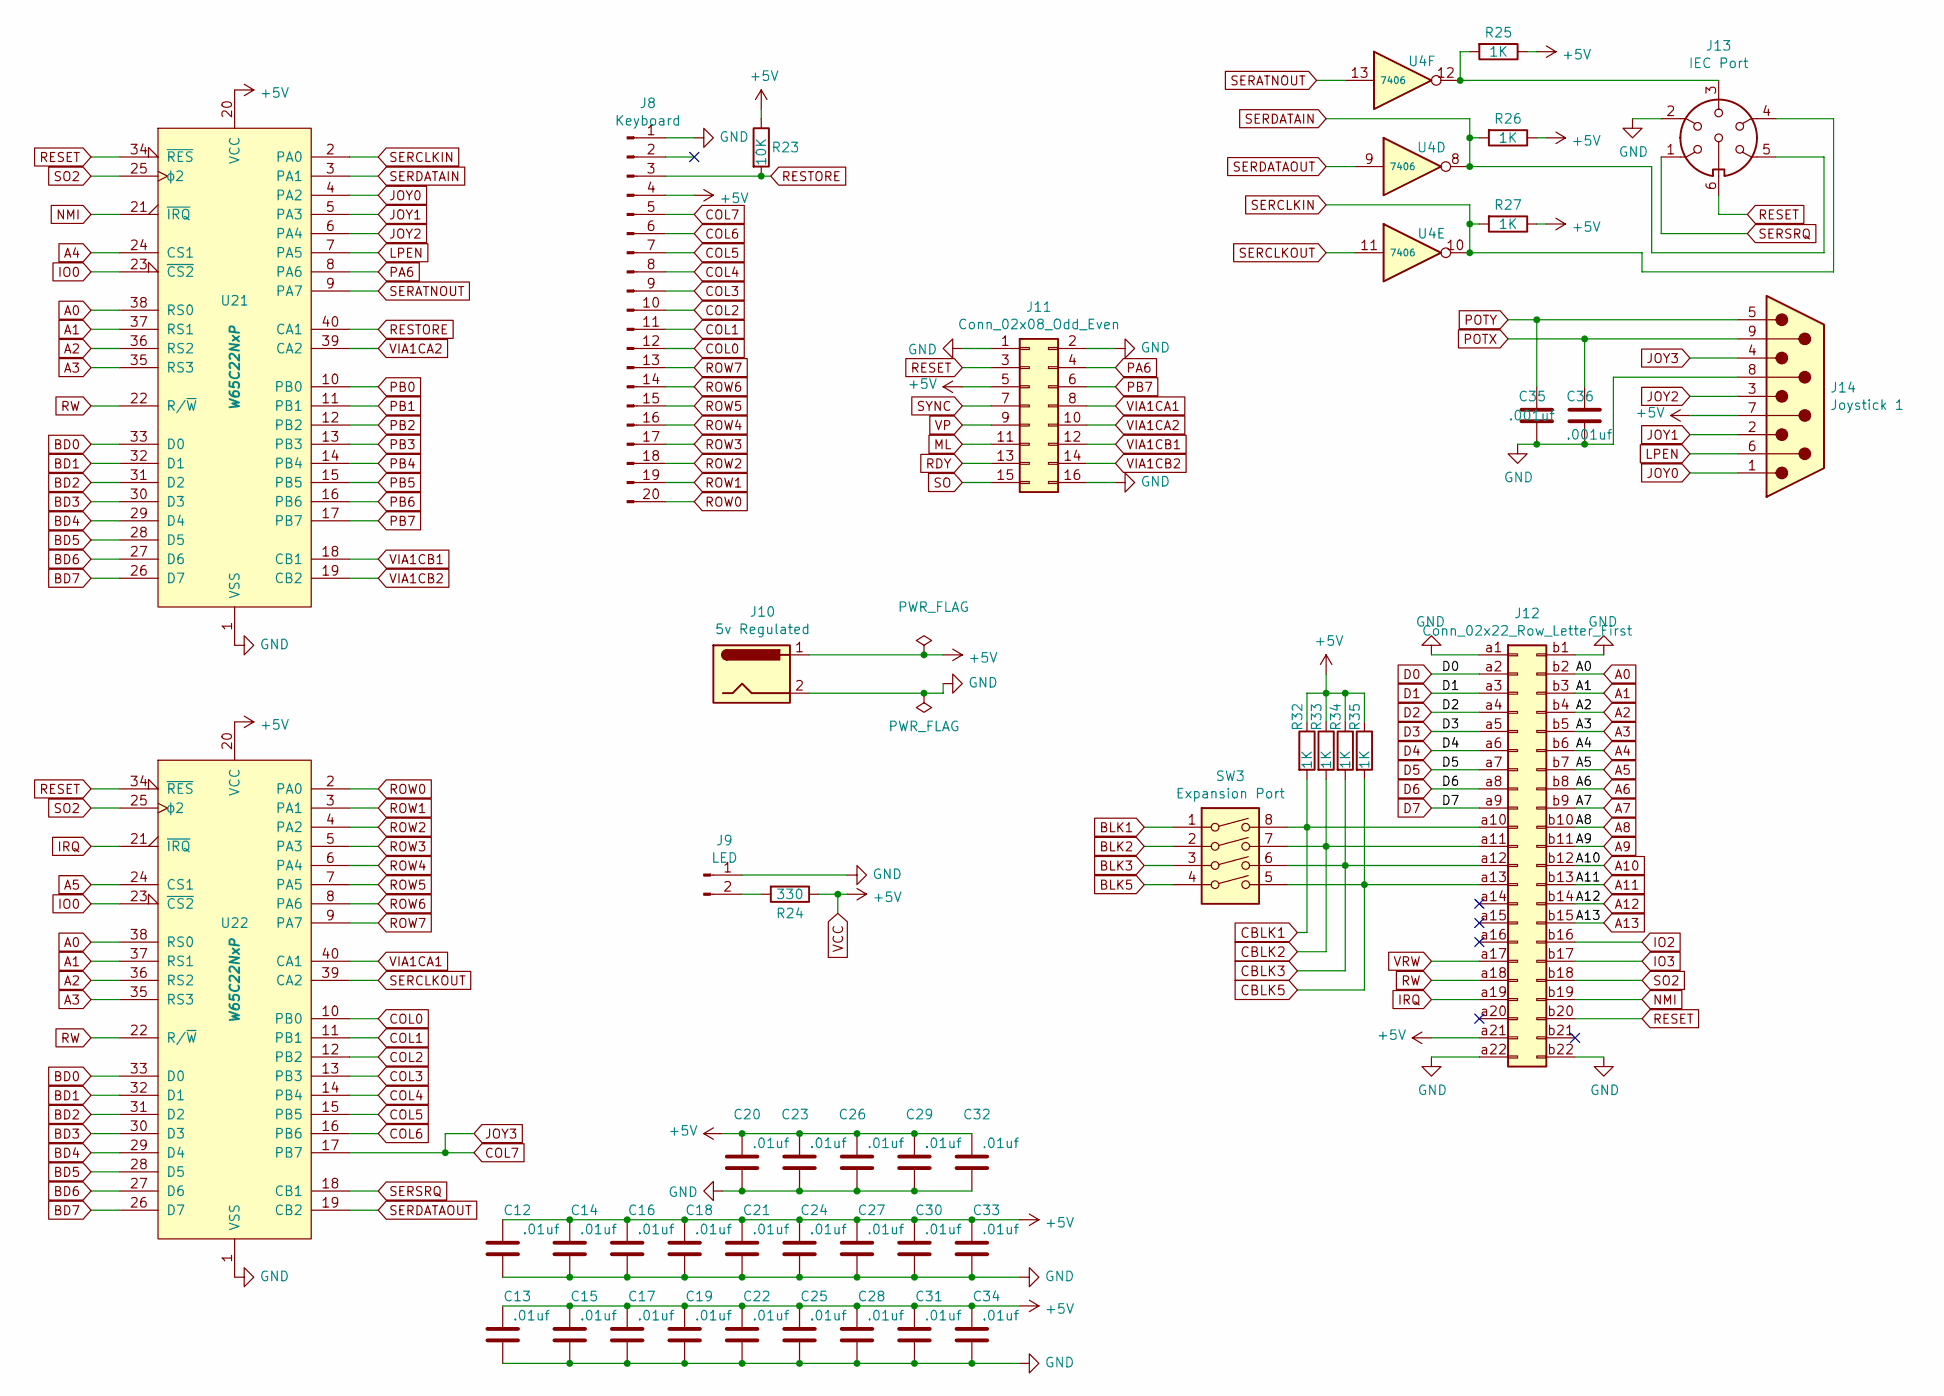
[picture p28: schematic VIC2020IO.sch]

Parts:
C12, C13, C14, C15, C16, C17, C18, C19, C20, C21, C22, C23, C24, C25, C26, C27, C28, C29, C30, C31, C32, C33, C34: .01uf; C_Rect_L7.0mm_W2.0mm_P5.00mm
C35, C36: .001uf; C_Rect_L7.0mm_W2.0mm_P5.00mm
J8: Keyboard; PinHeader_1x20_P2.54mm_Vertical
J9: LED; PinHeader_1x02_P2.54mm_Vertical
J10: 5v Regulated; BarrelJack_CUI_PJ-063AH_Horizontal
J11: Conn_02x08_Odd_Even; PinHeader_2x08_P2.54mm_Vertical
J12: Conn_02x22_Row_Letter_First; vic20cartridge1
J13: IEC Port; din6
J14: Joystick 1; DSUB-9_Male_Horizontal_P2.77x2.84mm_EdgePinOffset4.94mm_Hou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
R23: 10K; R_Axial_DIN0207_L6.3mm_D2.5mm_P7.62mm_Horizontal
R24: 330; R_Axial_DIN0207_L6.3mm_D2.5mm_P7.62mm_Horizontal
R25, R26, R27, R32, R33, R34, R35: 1K; R_Axial_DIN0207_L6.3mm_D2.5mm_P7.62mm_Horizontal
SW3: Expansion Port; DIP-8_W7.62mm
U4: 7406; DIP-14_W7.62mm_Socket
U21, U22: W65C22NxP; DIP-40_W15.24mm_Socket

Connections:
A0: J12.b2, U21.38 (RS0), U22.38 (RS0); also elsewhere on the board
A1: J12.b3, U21.37 (RS1), U22.37 (RS1); also elsewhere on the board
A2: J12.b4, U21.36 (RS2), U22.36 (RS2); also elsewhere on the board
A3: J12.b5, U21.35 (RS3), U22.35 (RS3); also elsewhere on the board
A4: J12.b6, U21.24 (CS1); also elsewhere on the board
A5: J12.b7, U22.24 (CS1); also elsewhere on the board
A6: J12.b8; also elsewhere on the board
A7: J12.b9; also elsewhere on the board
A8: J12.b10; also elsewhere on the board
A9: J12.b11; also elsewhere on the board
A10: J12.b12; also elsewhere on the board
A11: J12.b13; also elsewhere on the board
A12: J12.b14; also elsewhere on the board
A13: J12.b15; also elsewhere on the board
BD0: U21.33 (D0), U22.33 (D0); also elsewhere on the board
BD1: U21.32 (D1), U22.32 (D1); also elsewhere on the board
BD2: U21.31 (D2), U22.31 (D2); also elsewhere on the board
BD3: U21.30 (D3), U22.30 (D3); also elsewhere on the board
BD4: U21.29 (D4), U22.29 (D4); also elsewhere on the board
BD5: U21.28 (D5), U22.28 (D5); also elsewhere on the board
BD6: U21.27 (D6), U22.27 (D6); also elsewhere on the board
BD7: U21.26 (D7), U22.26 (D7); also elsewhere on the board
BLK1: SW3.1; also elsewhere on the board
BLK2: SW3.2; also elsewhere on the board
BLK3: SW3.3; also elsewhere on the board
BLK5: SW3.4; also elsewhere on the board
CBLK1: J12.a10, R32.2, SW3.8; also elsewhere on the board
CBLK2: J12.a11, R33.2, SW3.7; also elsewhere on the board
CBLK3: J12.a12, R34.2, SW3.6; also elsewhere on the board
CBLK5: J12.a13, R35.2, SW3.5; also elsewhere on the board
COL0: J8.12, U22.10 (PB0)
COL1: J8.11, U22.11 (PB1)
COL2: J8.10, U22.12 (PB2)
COL3: J8.9, U22.13 (PB3)
COL4: J8.8, U22.14 (PB4)
COL5: J8.7, U22.15 (PB5)
COL6: J8.6, U22.16 (PB6)
COL7: J8.5, J14.4, U22.17 (PB7)
D0: J12.a2; also elsewhere on the board
D1: J12.a3; also elsewhere on the board
D2: J12.a4; also elsewhere on the board
D3: J12.a5; also elsewhere on the board
D4: J12.a6; also elsewhere on the board
D5: J12.a7; also elsewhere on the board
D6: J12.a8; also elsewhere on the board
D7: J12.a9; also elsewhere on the board
GND: C12.2, C13.2, C14.2, C15.2, C16.2, C17.2, C18.2, C19.2, C20.2, C21.2, C22.2, C23.2, C24.2, C25.2, C26.2, C27.2, C28.2, C29.2, C30.2, C31.2, C32.2, C33.2, C34.2, C35.2, C36.2, J8.1, J9.1, J10.2, J11.1, J11.2, J11.16, J12.a1, J12.a22, J12.b1, J12.b22, J13.2, J14.8, U21.1 (VSS), U22.1 (VSS); also elsewhere on the board
IO0: U21.23 (~CS2), U22.23 (~CS2); also elsewhere on the board
IO2: J12.b16; also elsewhere on the board
IO3: J12.b17; also elsewhere on the board
IRQ: J12.a19, U22.21 (~IRQ); also elsewhere on the board
JOY0: J14.1, U21.4 (PA2)
JOY1: J14.2, U21.5 (PA3)
JOY2: J14.3, U21.6 (PA4)
LPEN: J14.6, U21.7 (PA5); also elsewhere on the board
ML: J11.11; also elsewhere on the board
NMI: J12.b19, U21.21 (~IRQ); also elsewhere on the board
unnamed: J9.2, R24.2
unnamed: J13.3, R25.2, U4.12
PA6: J11.4, U21.8 (PA6)
PB0: U21.10 (PB0); also elsewhere on the board
PB1: U21.11 (PB1); also elsewhere on the board
PB2: U21.12 (PB2); also elsewhere on the board
PB3: U21.13 (PB3); also elsewhere on the board
PB4: U21.14 (PB4); also elsewhere on the board
PB5: U21.15 (PB5); also elsewhere on the board
PB6: U21.16 (PB6); also elsewhere on the board
PB7: J11.6, U21.17 (PB7)
POTX: C36.1, J14.9; also elsewhere on the board
POTY: C35.1, J14.5; also elsewhere on the board
RDY: J11.13, J11.15; also elsewhere on the board
RESET: J11.3, J12.b20, J13.6, U21.34 (~RES), U22.34 (~RES); also elsewhere on the board
RESTORE: J8.3, R23.2, U21.40 (CA1)
ROW0: J8.20, U22.2 (PA0)
ROW1: J8.19, U22.3 (PA1)
ROW2: J8.18, U22.4 (PA2)
ROW3: J8.17, U22.5 (PA3)
ROW4: J8.16, U22.6 (PA4)
ROW5: J8.15, U22.7 (PA5)
ROW6: J8.14, U22.8 (PA6)
ROW7: J8.13, U22.9 (PA7)
RW: J12.a18, U21.22 (R/~W), U22.22 (R/~W); also elsewhere on the board
SERATNOUT: U4.13, U21.9 (PA7)
SERCLKIN: J13.4, R27.2, U4.10, U21.2 (PA0)
SERCLKOUT: U4.11, U22.39 (CA2)
SERDATAIN: J13.5, R26.2, U4.8, U21.3 (PA1)
SERDATAOUT: U4.9, U22.19 (CB2)
SERSRQ: J13.1, U22.18 (CB1)
SO2: J12.b18, U21.25 (ϕ2), U22.25 (ϕ2); also elsewhere on the board
SYNC: J11.7; also elsewhere on the board
VCC: C12.1, C13.1, C14.1, C15.1, C16.1, C17.1, C18.1, C19.1, C20.1, C21.1, C22.1, C23.1, C24.1, C25.1, C26.1, C27.1, C28.1, C29.1, C30.1, C31.1, C32.1, C33.1, C34.1, J8.4, J10.1, J11.5, J12.a21, J14.7, R23.1, R24.1, R25.1, R26.1, R27.1, R32.1, R33.1, R34.1, R35.1, U21.20 (VCC), U22.20 (VCC); also elsewhere on the board
VIA1CA1: J11.8, U22.40 (CA1)
VIA1CA2: J11.10, U21.39 (CA2)
VIA1CB1: J11.12, U21.18 (CB1)
VIA1CB2: J11.14, U21.19 (CB2)
VP: J11.9; also elsewhere on the board
VRW: J12.a17; also elsewhere on the board

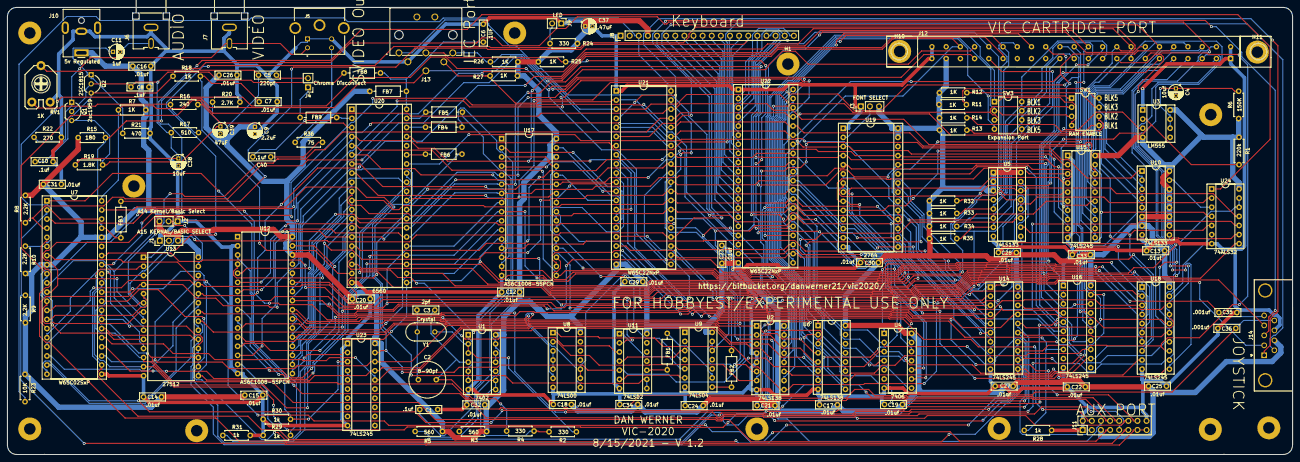
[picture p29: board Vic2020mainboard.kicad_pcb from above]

Board: 2 copper layers, 357.8 x 124.5 mm, 142 parts (0 on the bottom side), 186 nets.

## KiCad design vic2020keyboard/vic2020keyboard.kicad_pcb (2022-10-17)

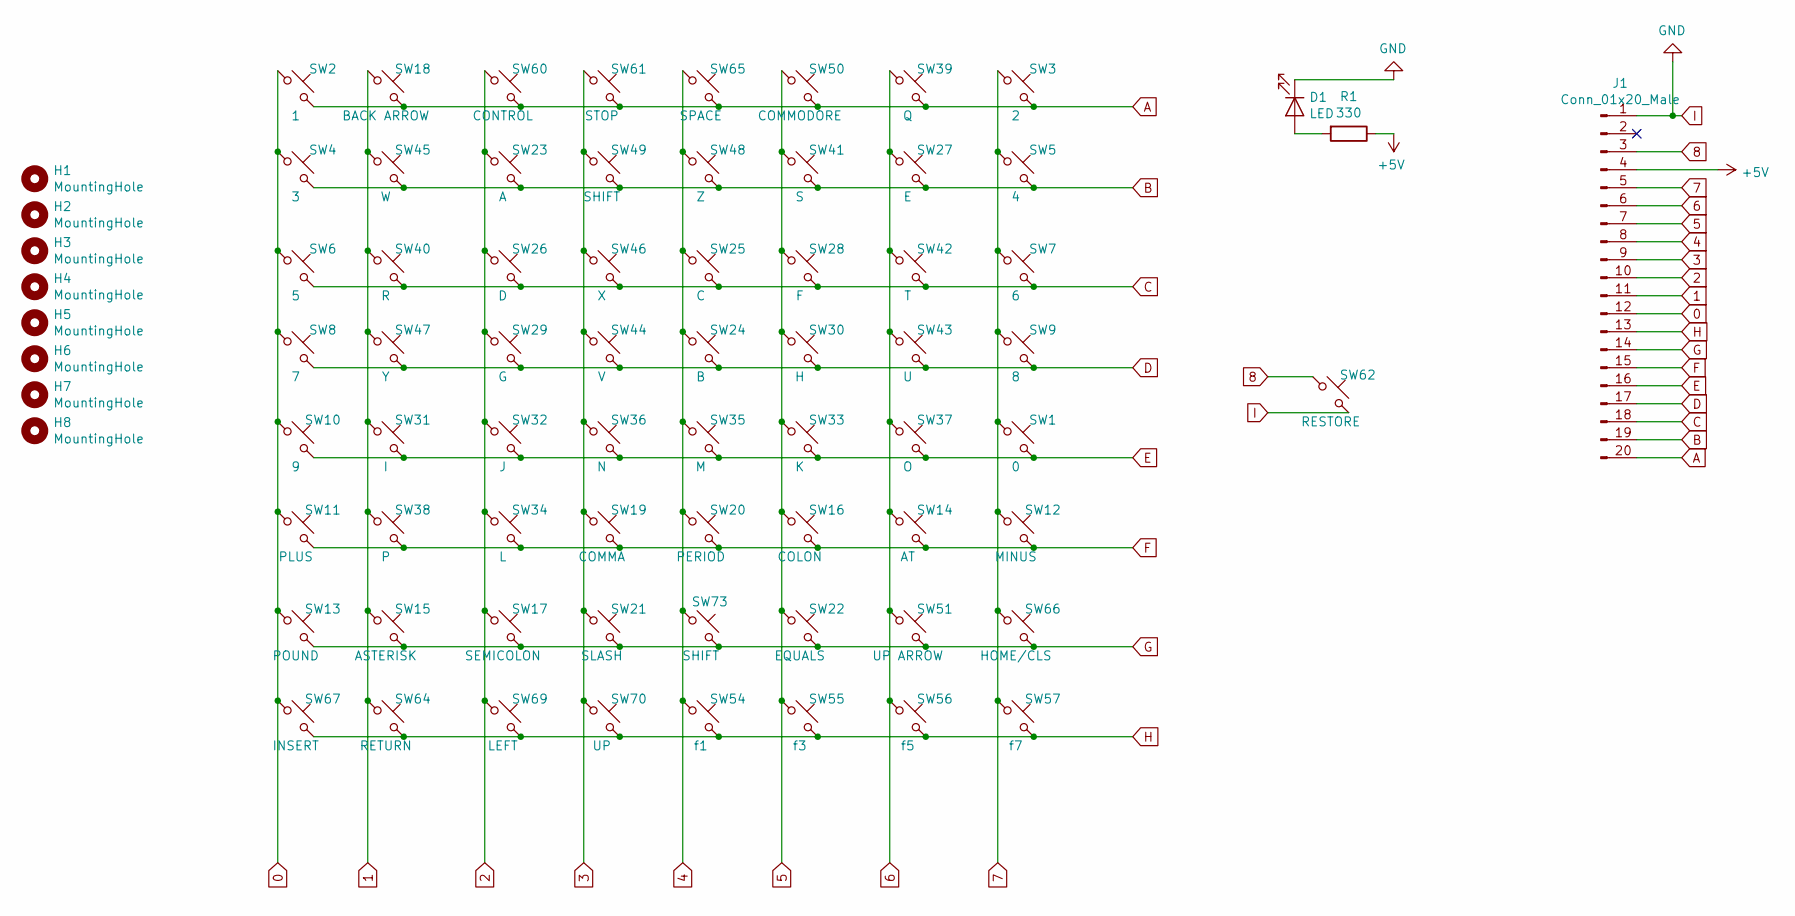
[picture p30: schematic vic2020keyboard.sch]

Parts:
D1: LED; LED_D5.0mm
H1, H2, H3, H4, H5, H6, H7, H8: MountingHole; MountingHole_3.2mm_M3_Pad
J1: Conn_01x20_Male; PinHeader_1x20_P2.54mm_Vertical
R1: 330; R_Axial_DIN0414_L11.9mm_D4.5mm_P7.62mm_Vertical
SW1: 0; CHERRY_PCB_100H
SW2: 1; CHERRY_PCB_100H
SW3: 2; CHERRY_PCB_100H
SW4: 3; CHERRY_PCB_100H
SW5: 4; CHERRY_PCB_100H
SW6: 5; CHERRY_PCB_100H
SW7: 6; CHERRY_PCB_100H
SW8: 7; CHERRY_PCB_100H
SW9: 8; CHERRY_PCB_100H
SW10: 9; CHERRY_PCB_100H
SW11: PLUS; CHERRY_PCB_100H
SW12: MINUS; CHERRY_PCB_100H
SW13: POUND; SW_Cherry_MX_1.00u_PCB
SW14: AT; CHERRY_PCB_100H
SW15: ASTERISK; CHERRY_PCB_100H
SW16: COLON; CHERRY_PCB_100H
SW17: SEMICOLON; CHERRY_PCB_100H
SW18: BACK ARROW; CHERRY_PCB_100H
SW19: COMMA; CHERRY_PCB_100H
SW20: PERIOD; CHERRY_PCB_100H
SW21: SLASH; CHERRY_PCB_100H
SW22: EQUALS; SW_Cherry_MX_1.00u_PCB
SW23: A; CHERRY_PCB_100H
SW24: B; CHERRY_PCB_100H
SW25: C; CHERRY_PCB_100H
SW26: D; CHERRY_PCB_100H
SW27: E; CHERRY_PCB_100H
SW28: F; CHERRY_PCB_100H
SW29: G; CHERRY_PCB_100H
SW30: H; CHERRY_PCB_100H
SW31: I; CHERRY_PCB_100H
SW32: J; CHERRY_PCB_100H
SW33: K; CHERRY_PCB_100H
SW34: L; CHERRY_PCB_100H
SW35: M; CHERRY_PCB_100H
SW36: N; CHERRY_PCB_100H
SW37: O; CHERRY_PCB_100H
SW38: P; CHERRY_PCB_100H
SW39: Q; CHERRY_PCB_100H
SW40: R; CHERRY_PCB_100H
SW41: S; CHERRY_PCB_100H
SW42: T; CHERRY_PCB_100H
SW43: U; CHERRY_PCB_100H
SW44: V; CHERRY_PCB_100H
SW45: W; CHERRY_PCB_100H
SW46: X; CHERRY_PCB_100H
SW47: Y; CHERRY_PCB_100H
SW48: Z; CHERRY_PCB_100H
SW49: SHIFT; CHERRY_PCB_225H
SW50: COMMODORE; CHERRY_PCB_125H
SW51: UP ARROW; SW_Cherry_MX_1.00u_PCB
SW54: f1; CHERRY_PCB_100H
SW55: f3; CHERRY_PCB_100H
SW56: f5; CHERRY_PCB_100H
SW57: f7; CHERRY_PCB_100H
SW60: CONTROL; SW_Cherry_MX_1.50u_PCB
SW61: STOP; SW_Cherry_MX_1.75u_PCB
SW62: RESTORE; SW_Cherry_MX_1.50u_PCB
SW64: RETURN; CHERRY_PCB_225H
SW65: SPACE; CHERRY_PCB_625H
SW66: HOME/CLS; CHERRY_PCB_100H
SW67: INSERT; CHERRY_PCB_100H
SW69: LEFT; CHERRY_PCB_100H
SW70: UP; CHERRY_PCB_100H
SW73: SHIFT; CHERRY_PCB_275H

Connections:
0: J1.12, SW2.1, SW4.1, SW6.1, SW8.1, SW10.1, SW11.1, SW13.1, SW67.1
1: J1.11, SW15.1, SW18.1, SW31.1, SW38.1, SW40.1, SW45.1, SW47.1, SW64.1
2: J1.10, SW17.1, SW23.1, SW26.1, SW29.1, SW32.1, SW34.1, SW60.1, SW69.1
3: J1.9, SW19.1, SW21.1, SW36.1, SW44.1, SW46.1, SW49.1, SW61.1, SW70.1
4: J1.8, SW20.1, SW24.1, SW25.1, SW35.1, SW48.1, SW54.1, SW65.1, SW73.1
5: J1.7, SW16.1, SW22.1, SW28.1, SW30.1, SW33.1, SW41.1, SW50.1, SW55.1
6: J1.6, SW14.1, SW27.1, SW37.1, SW39.1, SW42.1, SW43.1, SW51.1, SW56.1
7: J1.5, SW1.1, SW3.1, SW5.1, SW7.1, SW9.1, SW12.1, SW57.1, SW66.1
8: J1.3, SW62.1
+5V: J1.4, R1.1
A: J1.20, SW2.2, SW3.2, SW18.2, SW39.2, SW50.2, SW60.2, SW61.2, SW65.2
B: J1.19, SW4.2, SW5.2, SW23.2, SW27.2, SW41.2, SW45.2, SW48.2, SW49.2
C: J1.18, SW6.2, SW7.2, SW25.2, SW26.2, SW28.2, SW40.2, SW42.2, SW46.2
D: J1.17, SW8.2, SW9.2, SW24.2, SW29.2, SW30.2, SW43.2, SW44.2, SW47.2
E: J1.16, SW1.2, SW10.2, SW31.2, SW32.2, SW33.2, SW35.2, SW36.2, SW37.2
F: J1.15, SW11.2, SW12.2, SW14.2, SW16.2, SW19.2, SW20.2, SW34.2, SW38.2
G: J1.14, SW13.2, SW15.2, SW17.2, SW21.2, SW22.2, SW51.2, SW66.2, SW73.2
H: J1.13, SW54.2, SW55.2, SW56.2, SW57.2, SW64.2, SW67.2, SW69.2, SW70.2
I: D1.1 (K), J1.1, SW62.2
unnamed: D1.2 (A), R1.2

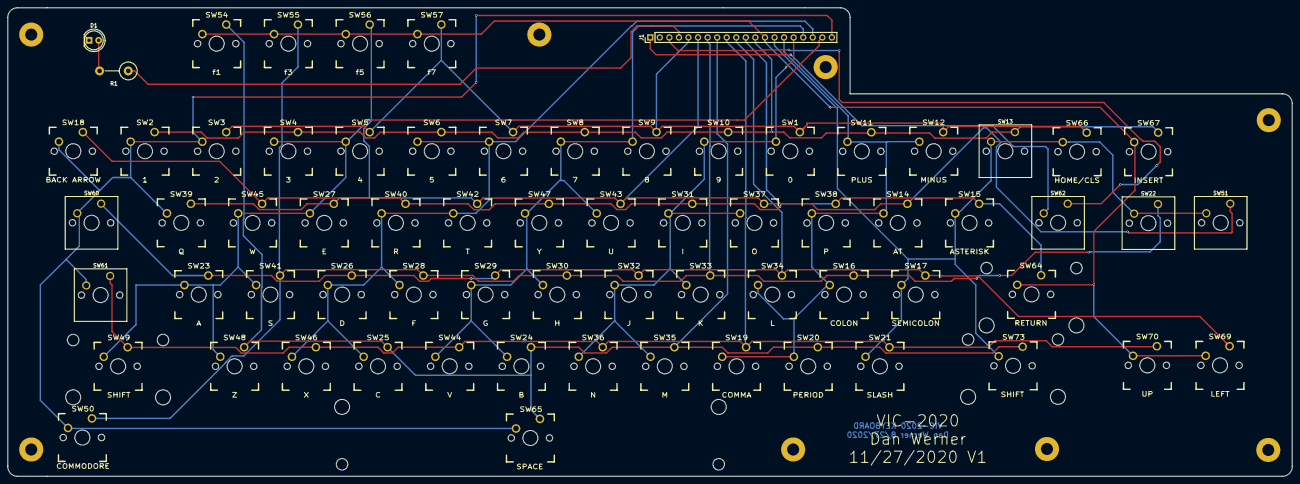
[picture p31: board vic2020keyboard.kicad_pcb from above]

Board: 2 copper layers, 341.2 x 124.5 mm, 76 parts (0 on the bottom side), 20 nets.

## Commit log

2020-12-12 Initial docs
    [Vic2020mainboard-BOM.xlsx]
2020-12-13 Case Changes . . . enlarge case for proper cartridge fit
    [Vic2020case.scad]
2020-12-13 Case Changes . . . add LED opening
    [Vic2020case.scad, Vic2020case_Top.stl]
2020-12-15 Case Changes . . . final tweaks
    [Vic2020case.scad, Vic2020case_Top.stl]
2020-12-24 modify cartridge opening
    [Vic2020case.scad, Vic2020case_Top.stl]
2020-12-25 Add Keyboard Spacer
    [Vic2020case.scad, Vic2020case_Keyboard_spacer.stl]
2021-01-04 added case pictures
2021-04-03 Correct SVIDEO connector footprint
    [VIC2020DISPLAY.sch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]
2021-08-04 update PCB
    [VIC2020DISPLAY.sch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]
2021-08-16 Fix SVIDEO (again)
    [VIC2020DISPLAY.sch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]
2022-10-17 doc updates
    [VIC2020DISPLAY.sch, VIC2020IO.sch, Vic2020case.scad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]
